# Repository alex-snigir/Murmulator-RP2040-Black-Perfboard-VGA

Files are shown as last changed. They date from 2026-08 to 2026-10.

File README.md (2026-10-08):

*Read this document in English: [README_EN.md](README_EN.md)*

# Мурмулятор — RP2040 Black Clone, VGA-сборка на перфборде

Сборка Мурмулятора (переходной платы от Raspberry Pi Pico / клона YD-RP2040 к периферии) с VGA-выходом, PS/2-клавиатурой, двумя джойстик-портами (с поддержкой Bluetooth-геймпадов через BlueRetro), аудиовыходом, аудиовходом для загрузки программ, слотом MicroSD и внешним питанием. Плата собирается на перфборде, схема разведена в KiCad.

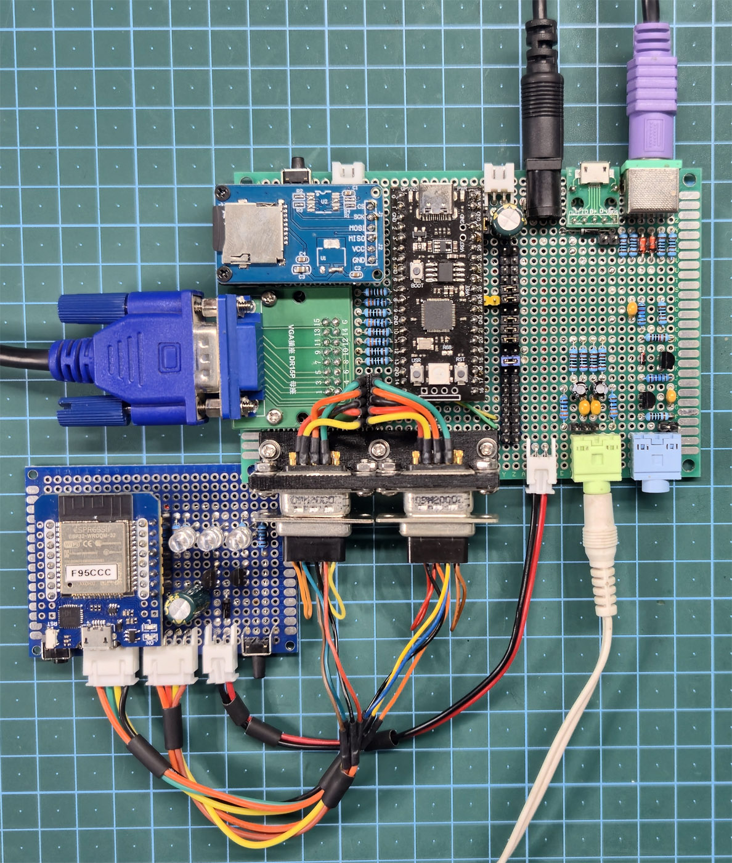
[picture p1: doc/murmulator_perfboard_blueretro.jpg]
Murmulator PCB


## Разъёмы платы

| Разъём | Назначение |
|---|---|
| J1 | Внешнее питание (PSU), DC Jack → шина `+5V_RAW` |
| J2 | Отвод шины `+5V_RAW` — для внешней периферии (BlueRetro) |
| J3 | VGA (12-контактная гребёнка, Conn_02x06) |
| J4 | Клавиатура (PS/2, Mini-DIN-6) |
| J5 | Внешний разъём (EXT, 40 пинов); пары пинов с джамперами подключают PS/2, звук и аудиовход к GPIO |
| J6 | Джойстик 1 (DE-9) |
| J7 | Джойстик 2 (DE-9) |
| J8 | Аудиовыход |
| J9 | Аудиовход (загрузка программ с TAP/магнитофона) |
| J10 | Отвод `+3V3` (JST-XH) |
| J11 | Отвод узла `+5V_VOUT` (тот же узел, что и клавиатура J4) |
| J12 | Второй вход питания от USB (модуль Micro USB) вместо DC-джека → через D1 на шину `+5V_RAW` |
| J13 | Селектор (перемычка): `+5V_RAW` → Vin (штатно) или → Vout |
| J14 | Перемычка в обход D1 |
| J15 | Модуль MicroSD (SPI) |
| J16 | Дубль J2 на другой стороне платы |

## Документация

- [`doc/murmulator-vga-project-summary.md`](doc/murmulator-vga-project-summary.md) — полное описание сборки (RU): доработка SD-модуля, VGA, PS/2-клавиатура, джойстики и интеграция BlueRetro, аудиовыход и аудиовход, разъём J5, питание, чек-лист сборки. Английская версия: [`doc/murmulator-vga-project-summary_EN.md`](doc/murmulator-vga-project-summary_EN.md).
- [`doc/rp2040-module-powerchain-analysis.md`](doc/rp2040-module-powerchain-analysis.md) — сравнение цепей питания YD-RP2040 (Black Clone) и официального Raspberry Pi Pico. Английская версия: [`doc/rp2040-module-powerchain-analysis_EN.md`](doc/rp2040-module-powerchain-analysis_EN.md).
- [`doc/Firmware/technocat-murmulator-keyboard-mapping.md`](doc/Firmware/technocat-murmulator-keyboard-mapping.md) — маппинг PS/2-клавиатуры на ZX Spectrum в прошивке Tecnocat v0.96.20, разбор режима «Cursor joystick». Английская версия: [`doc/Firmware/technocat-murmulator-keyboard-mapping_EN.md`](doc/Firmware/technocat-murmulator-keyboard-mapping_EN.md).
- [`doc/murmulator-ps2-modifiers-oscillograms.pdf`](doc/murmulator-ps2-modifiers-oscillograms.pdf) — осциллограммы PS/2-сигналов CLK/DATA для клавиш-модификаторов ([DOCX](doc/murmulator-ps2-modifiers-oscillograms.docx)). Английская версия: [PDF](doc/murmulator-ps2-modifiers-oscillograms_EN.pdf), [DOCX](doc/murmulator-ps2-modifiers-oscillograms_EN.docx).
- [`doc/murmulator_perfboard_front.jpg`](doc/murmulator_perfboard_front.jpg) — фото платы на перфборде (front).
- [`doc/murmulator_perfboard_back.jpg`](doc/murmulator_perfboard_back.jpg) — фото платы на перфборде (back).

## Схемы (KiCad)

- [`schematics/rp2040_black_vga/`](schematics/rp2040_black_vga/) — исходные файлы проекта KiCad.
- [`schematics/rp2040_black_vga/plot/rp2040_black_vga.pdf`](schematics/rp2040_black_vga/plot/rp2040_black_vga.pdf) — принципиальная схема в PDF.
- [`schematics/rp2040_black_vga/plot/rp2040_black_vga.net`](schematics/rp2040_black_vga/plot/rp2040_black_vga.net) — нетлист.

## Справочные материалы

- [`doc/YD-2040-2022-V1.1-Schematics_black_clone.pdf`](doc/YD-2040-2022-V1.1-Schematics_black_clone.pdf) — схема модуля YD-RP2040 (Black Clone).
- [`doc/YD-2040-2022-V1.1 - Powerchain.jpg`](<doc/YD-2040-2022-V1.1 - Powerchain.jpg>), [`doc/RP2040 Official Pico Module - Powerchain.jpg`](<doc/RP2040 Official Pico Module - Powerchain.jpg>) — фрагменты схем питания клона и официального Pico.
- [`doc/original_classic_murmulator_37NJU22_emul_RPPICO_card.pdf`](doc/original_classic_murmulator_37NJU22_emul_RPPICO_card.pdf) — оригинальная классическая схема Мурмулятора.
- [`doc/FT SD Module modification.jpg`](<doc/FT SD Module modification.jpg>) — доработка SD-модуля.

## Ключевые особенности сборки

- **SD-модуль** доработан: выпаяны AMS1117 и буфер 74VHCT125A, установлены перемычки — модуль работает как чистый 3.3V breakout без потери фронтов на высокой скорости SPI.
- **VGA** — пассивная резисторная R2R-лесенка на GPIO, без отдельного питания.
- **PS/2-клавиатура** — питание от Vout (после диода BAT54C), сигнальные линии CLK/DATA согласованы по уровню резистивно-зенерной схемой (5V → 3.3V).
- **Джойстики (Dendy, DE-9)** — сдвиговый регистр запитан от 3.3V, что снимает необходимость в защитных резисторах на DATA.
- **BlueRetro** — DIY-адаптер на ESP32 эмулирует оба джойстик-порта по Bluetooth HID (PS3/4/5, Xbox, Wii/Switch и др.), протокол CLOCK/LATCH/DATA идентичен физическому Dendy-джойстику. Требует питания на J1 или J12. Сборка адаптера на 3.3V-логике: https://github.com/alex-snigir/BlueRetro-3.3V-logic
- **Аудиовыход** — стереоканал (L/R) плюс подмешивание сигнала пищалки (BEEP_OUT).
- **Аудиовход** — двухкаскадный формирователь на транзисторах для загрузки программ с TAP-сигнала (магнитофон, телефон, онлайн-плеер TAP).
- **Питание** — шина `+5V_RAW` от DC-джека J1 или от Micro USB J12 (через диод Шоттки D1), селектор J13 подаёт её на Vin модуля (штатно, через встроенный BAT54C) или напрямую на Vout в обход маломощного BAT54C.

Подробности по каждому пункту — в [`doc/murmulator-vga-project-summary.md`](doc/murmulator-vga-project-summary.md).

## Корпус

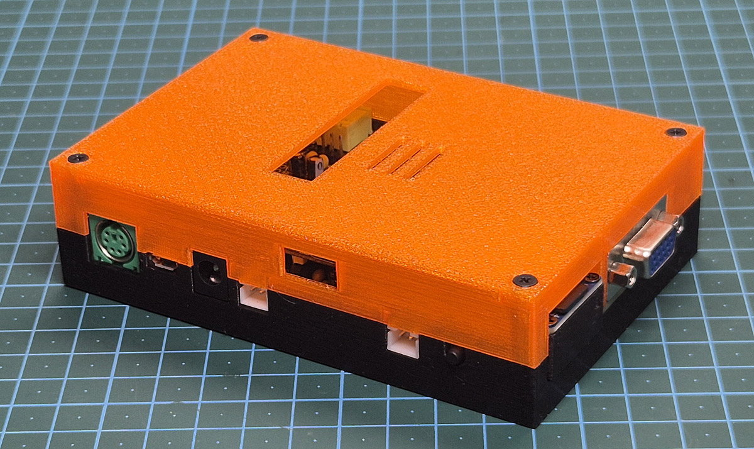
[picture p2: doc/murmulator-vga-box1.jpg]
Murmulator BOX1

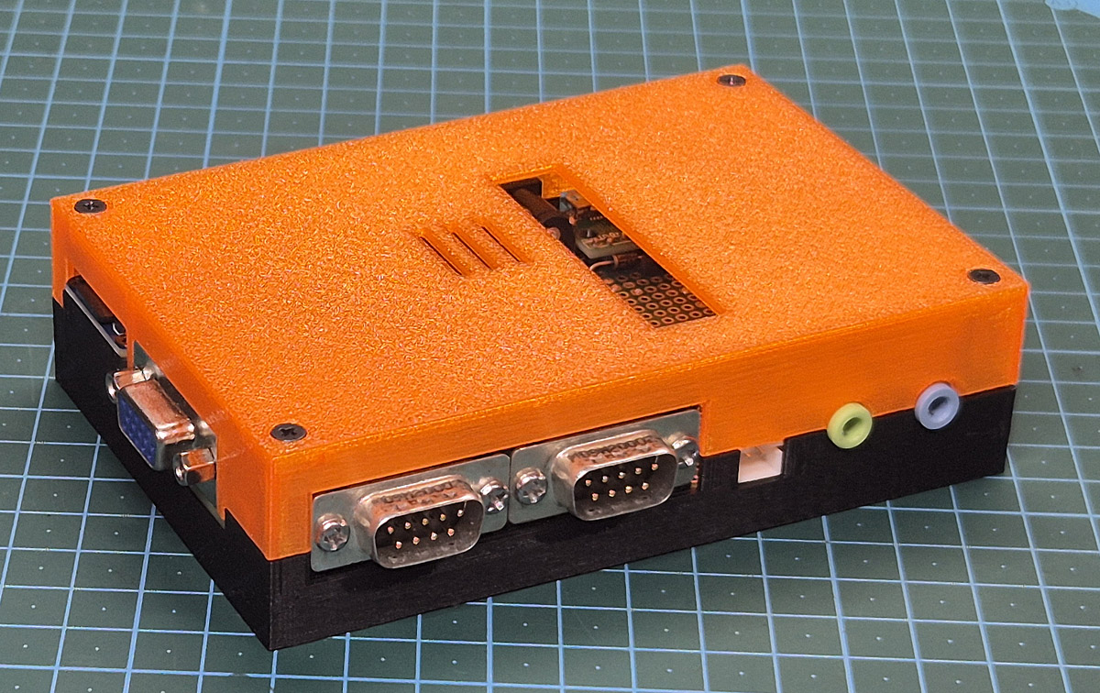
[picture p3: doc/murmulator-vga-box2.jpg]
Murmulator BOX2


### 3D-модели для печати

Файлы лежат в папке [`3d models/`](<3d models/>):

| Деталь | Файлы |
|---|---|
| Корпус (дно + крышка) | [`Box_Bottom_v2.STL`](<3d models/Box_Bottom_v2.STL>) + [`Box_Cover_v2.STL`](<3d models/Box_Cover_v2.STL>) |
| Только плоское дно, без крышки | [`Box_Bottom.STL`](<3d models/Box_Bottom.STL>) |
| Крепление для двух разъёмов DB9 (джойстики J6/J7) | [`DB9_x2_mount.STL`](<3d models/DB9_x2_mount.STL>) |
| Опора для SD-модуля | [`SD_module_support.STL`](<3d models/SD_module_support.STL>) |

Рядом лежат исходники SolidWorks (`.SLDPRT`) и проекты слайсера (`.3mf`) с теми же именами.

## Ссылки

- Официальная документация и другие варианты сборки Мурмулятора: https://murmulator.ru/howto
- Классическая схема (референс): https://github.com/AlexEkb4ever/MURMULATOR_classical_scheme
- Базовая версия «Мурмулятор на макетной плате 7×9 с VGA»: https://murmulator.ru/mm-maket
- BlueRetro-адаптер на 3.3V-логике (интеграция джойстик-портов): https://github.com/alex-snigir/BlueRetro-3.3V-logic
- Прошивка Tecnocat (Murmulator_rp2040): https://github.com/MadedCat/Murmulator_rp2040

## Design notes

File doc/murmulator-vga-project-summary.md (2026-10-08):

# Сборка VGA-Мурмулятора на перфборде

**Версия документа:** 1.0 · **Дата:** 2026-10-03

## 1. Общая концепция

Мурмулятор — плата-переходник от Raspberry Pi Pico к периферии (SD-карта, VGA, PS/2-клавиатура, джойстик, аудиозагрузка).

**Обозначения разъёмов на плате:**

| Разъём | Назначение |
|---|---|
| J1 | Внешнее питание (PSU), DC Jack → шина `+5V_RAW` |
| J2 | Отвод шины `+5V_RAW` — для внешней периферии, напр. BlueRetro |
| J3 | VGA (12-контактная гребёнка, Conn_02x06) |
| J4 | Клавиатура (PS/2, Mini-DIN-6) |
| J5 | Внешний разъём (external connector) |
| J6 | Джойстик 1 (DE-9) |
| J7 | Джойстик 2 (DE-9) |
| J8 | Аудиовыход (audio out) |
| J9 | Аудиовход (audio in) |
| J10 | Отвод `+3V3` (JST-XH, 2 пина: GND, +3V3) |
| J11 | Доп. отвод узла `+5V_VOUT` («Power 5V Out») — для внешней периферии, запитанной после диодного ИЛИ (тот же узел, что и клавиатура J4) |
| J12 | Второй вход питания от USB (модуль Micro USB) вместо DC-джека → через D1 на шину `+5V_RAW` |
| J13 | Селектор (перемычка): `+5V_RAW` → Vin (1–2, штатное положение) или → Vout (2–3) |
| J14 | Перемычка в обход D1 (когда диод не нужен) |
| J15 | Подключение модуля MicroSD (SPI, питание +3V3) |
| J16 | Дубль J2 (отвод `+5V_RAW`) на другой стороне PCB |

**Материалы:**
- Схема и документация: https://murmulator.ru/howto
- Страница класической схемы: https://github.com/AlexEkb4ever/MURMULATOR_classical_scheme

**Базовая версия:** сборка изначально опирается на документацию официального варианта «Мурмулятор на макетной плате 7×9 с VGA» — https://murmulator.ru/mm-maket (архив документации: https://file.murmulator.ru/data/murmulator-types/mm-maket/mm-docs.zip). Текущая версия расширяет её дополнительными функциями, оставаясь на перфборде.

**Связанные документы проекта:**
- `blueretro-murmulator-project-summary.md` — полная детализация DIY-сборки адаптера BlueRetro (выбор ESP32-платы, входная защита питания, LED-индикация, прошивка, осциллографическая проверка), согласована с разделом 5.1 ниже.
- `blueretro-murmulator-user-guide.md` — инструкции по пейрингу/отключению Bluetooth-геймпадов.

---

## 2. Доработка SD-модуля (AMS1117 + 74VHCT125A)

Стандартный дешёвый SD-модуль (5V/3.3V, SPI) требует доработки — иначе просадки/сбои при высокой скорости SPI.

| Элемент | Действие | Зачем |
|---|---|---|
| **AMS1117** (стабилизатор 3.3V) | Выпаять; подать 3.3V от Pico напрямую на площадку, где был выход стабилизатора (VCC карты) | Лишнее звено — Pico и так выдаёт чистые 3.3V, регулятор только добавляет просадку |
| **74VHCT125A** (буфер SPI, SOIC/TSSOP-14) | Выпаять; закоротить перемычками вход→выход на линиях SCK, MOSI, CS (и MISO, если тоже через буфер) | Задержка распространения сигнала через буфер портит фронты на высокой скорости SPI, из-за чего SD-карта сбоит |

**Порядок работ:**
1. Прозвонить мультиметром, какие дорожки на конкретном экземпляре модуля идут через каждую микросхему (ревизии отличаются).
2. Выпаять AMS1117 и 74VHCT125A **до** установки модуля на перфборд (удобнее работать феном/паяльником).
3. Запаять перемычки на месте выпаянных элементов.
4. Прозвонить на отсутствие КЗ между соседними дорожками.
5. Только после этого подключать питание 3.3V и линии SPI от Pico.

**Итог:** модуль превращается из «5V-адаптера с level-shifting» в чистый breakout SD-карты на 3.3V, без активных/пассивных элементов между Pico и картой на линиях данных.

**Подключение модуля MicroSD — разъём J15** (по нетлисту `rp2040_black_vga.net` от 2026-08-29):

| Пин J15 | Сигнал | GPIO Pico |
|---|---|---|
| 1 | GND | — |
| 2 | VCC | `+3V3` |
| 3 | MISO | GP4 |
| 4 | MOSI | GP3 |
| 5 | SCK | GP2 |
| 6 | CS | GP5 |

### 2.1. Pull-up резисторы на линиях SD-модуля

После выпайки 74VHCT125A нужно отдельно проверить/обеспечить подтяжку на двух линиях SPI:

| Линия | Нужна подтяжка? | Номинал | Зачем |
|---|---|---|---|
| **CS** | Да, обязательно | ~10 кОм к 3.3V | При неопределённом состоянии GPIO на старте Pico линия CS должна оставаться высокой (deselected), иначе карта может ловить шум с MOSI/CLK как команды |
| **MISO (DO)** | Желательно | ~10–50 кОм к 3.3V | Когда CS неактивен, выход карты уходит в Hi-Z — подтяжка не даёт линии «плавать» и наводить помехи |
| **MOSI, SCK** | Не требуется | — | Всегда активно управляются мастером (Pico), в Hi-Z не уходят |

**Что проверить на конкретном модуле:**
Некоторые дешёвые SD-модули разводят pull-up прямо возле буфера 74VHCT125A. После его выпайки и установки перемычек резисторы могли:
1. остаться в цепи независимо от буфера — тогда всё ок;
2. пропасть вместе с посадочным местом буфера — тогда нужно добавить отдельно.

**Порядок проверки:** прозвонить омметром между CS и 3.3V, и между MISO и 3.3V (заодно с проверкой на КЗ после перемычек из п.2). Конечное сопротивление (10–50 кОм) — резистор на месте. Обрыв — впаять 10 кОм резисторы от CS и MISO к шине 3.3V на перфборде.

**Подтверждено по нетлисту (`rp2040_black_vga.net`):** подтяжки уже заведены в схему — R28 (10 кОм) на CS (GP5) и R27 (10 кОм) на MISO (GP4), обе к сети `+3V3`. Соответствует рекомендации выше (CS ~10 кОм обязательно, MISO 10–50 кОм желательно).

*Симптом отсутствующей подтяжки CS: карта нестабильно определяется при старте («работает через раз»), что сложно диагностировать постфактум.*

---

## 3. VGA (J3)

- Резисторная R2R-лесенка на цифровые GPIO Pico — пассивная схема, отдельного питания не требует.
- VGA-разъём проще не покупать, а срезать готовый экранированный шлейф со старой видеокарты (часто там разъём есть, но не распаян).
- Резисторы паять компактно, вплотную к шлейфу/разъёму, короткими выводами — критично для чистоты картинки (наводки).

---

## 4. Клавиатура (PS/2, J4)

**Разъём:** J4 — Mini-DIN-6 (PS/2).

### 4.1. Питание клавиатуры

Клавиатура запитывается **отдельно от основной 3.3V-периферии**, напрямую с **Vout (пин 40 YD-RP2040)** — узла после диодного ИЛИ BAT54C, а не с 3V3(OUT). Подробнее — см. раздел 9 («Питание платы»).

| Параметр | Значение |
|---|---|
| Источник | Vout (после BAT54C), не 3V3(OUT) |
| Номинальное падение | ~0.3–0.45V на BAT54C относительно входного 5V (в штатном положении J13; при питании от J12 добавляется падение на D1, см. раздел 10) |
| Итоговое напряжение на пине 4 Mini-DIN-6 | 4.62–4.67V при питании от USB Type-C модуля или от J1 (измерено, в пределах допуска PS/2-спецификации); 4.04–4.29V при питании от J12 через D1 — см. измерения в разделе 10 |
| Ток потребления клавиатуры | ~100 мА (учитывать при бюджетировании тока через BAT54C, см. раздел 10) |

### 4.2. Сигнальные линии (level-shifting 5V → 3.3V)

PS/2 CLK и DATA — 5V-логика на стороне клавиатуры, GPIO Pico — 3.3V, не толерантны к 5V. Используется **пассивная схема** согласования уровней: pull-up резистор + последовательный резистор + зенер-клампа на каждой линии.

**Соответствие сигналов (по референсной схеме MURMULATOR_classical_scheme, KiCad):**

| Сигнал (raw, 5V, от клавиатуры) | После зенер-клампа | GPIO Pico |
|---|---|---|
| PS2 CLK (Mini-DIN-6, pin 5) | PS2_CLK_3V | GP0 |
| PS2 DATA (Mini-DIN-6, pin 1) | PS2_DATA_3V | GP1 |

**Фактическая схема линии (подтверждено по нетлисту `rp2040_black_vga.net`):**

```
J4 (5V raw) ──[R9/R10, 1 кОм, pull-up к +5V_VOUT]── узел CLK/DATA ──[R11/R12, 100 Ом]── GPIO (GP0/GP1) ──[D2/D3, зенер]── GND
```

| Элемент | Номинал | Роль |
|---|---|---|
| R9 (CLK) / R10 (DATA) | 1 кОм | Pull-up сырой 5V-линии к +5V_VOUT — обязателен, т.к. выход клавиатуры open-collector |
| R11 (CLK) / R12 (DATA) | 100 Ом | Последовательный резистор между сырой линией и GPIO — ограничивает ток через зенер при пробое, вместе с ёмкостью входа GPIO образует RC-фильтр |
| D2 (CLK) / D3 (DATA) | 3.3V | Катод на GPIO, анод на GND — клипирует верхний уровень сигнала на GPIO |

Схема: сырой 5V-сигнал (уже подтянутый к +5V_VOUT резистором R9/R10) → проходит через последовательный резистор R11/R12 (100 Ом) → зенер-клампа ограничивает верхний уровень на самом GPIO → сигнал поступает на GP0/GP1.

**Подключение к GPIO — через джамперы на J5 (по нетлисту `rp2040_black_vga.net` от 2026-10-03):** узлы `PS/2_DATA_3V` и `PS/2_CLK_3V` (после R11/R12, на катодах D2/D3) на плате не соединены с GPIO напрямую — они выведены на J5 (пины 29 и 31), а рядом выведены GP1 (пин 30) и GP0 (пин 32). Соединение выполняется джамперами J5:29–30 (DATA → GP1) и J5:31–32 (CLK → GP0); на схеме они обозначены перемычками NT5/NT6 (символы «Exclude from board», в нетлист и на плату не попадают).

---

## 5. Джойстики (Dendy, 2 порта, DE-9, J6/J7)

**Обозначения разъёмов на плате:** Джойстик 1 — **J6**, Джойстик 2 — **J7**.

Используются джойстики типа Dendy (9-pin, узкий разъём) — внутри активная микросхема сдвигового регистра (тип CD4021 или аналог), а не просто механические контакты.

**Распиновка DE-9 (Dendy 9-pin):**

| Пин DE-9 | Назначение |
|---|---|
| 2 | DATA — выход сдвигового регистра |
| 3 | LATCH — защёлка/сброс счётчика |
| 4 | CLOCK — тактовый импульс сдвига |
| 6 | +5V — штатное питание микросхемы регистра |
| 8 | GND |

**Почему регистр запитан от 3.3V, а не от штатных 5V:**
DATA-выход джойстика повторяет уровень его питания. При питании от 5V линия DATA становится 5V-логикой, а GPIO RP2040 не толерантны к 5V (макс. ~3.6V) — потребовался бы защитный резистор (~1 кОм) на DATA как грубое ограничение тока в защитный диод порта. Микросхемы регистра (CD4021-подобные) — обычная КМОП-логика с широким диапазоном питания (обычно 3–18V), поэтому запитка от 3.3V вместо 5V — штатное и безопасное решение: DATA получается сразу 3.3V-логикой, резистор не нужен, подключение к GPIO — напрямую.

**Итоговая схема подключения (2 порта):**

| Сигнал | Джойстик 1 (пин DE-9) | Джойстик 2 (пин DE-9) | GPIO Pico |
|---|---|---|---|
| DATA | 2 | 2 | GP16 (J6) / GP17 (J7) — раздельные |
| LATCH | 3 | 3 | GP15 — общий для обоих портов |
| CLOCK | 4 | 4 | GP14 — общий для обоих портов |
| VCC | 6 | 6 | 3.3V — общая шина |
| GND | 8 | 8 | GND — общая шина |

CLOCK и LATCH — общие для обоих джойстиков (оба регистра тактируются и защёлкиваются синхронно), DATA — обязательно раздельные линии на каждый порт, иначе выходы конфликтуют на одной линии.

**Распиновка джойстиков и прошивка — проверено:** прошивка Tecnocat работает с BlueRetro на текущем подключении (GP14 CLOCK, GP15 LATCH, GP16/GP17 DATA) без правки конфига. Ранее отмеченный открытый вопрос закрыт.

### 5.1. Интеграция BlueRetro (Bluetooth-геймпады вместо физических Dendy-джойстиков)

> 📄 **Полная детализация сборки BlueRetro** (выбор платы, входная защита питания, кнопка BOOT, LED-индикация, версия прошивки, осциллографическая проверка сигналов) вынесена в отдельный документ **`blueretro-murmulator-project-summary.md`**. Ниже — согласованная с ним сводка, достаточная для контекста основной сборки Мурмулятора.

Физических Dendy-джойстиков в проекте нет — оба DE-9-порта (J6/J7) изначально задуманы как **виртуальные**, обслуживаемые одним самодельным DIY-адаптером **BlueRetro** (ESP32, прошивка с github.com/darthcloud/BlueRetro — репозиторий заархивирован владельцем 14.12.2025, активной разработки больше нет, но релизы прошивки и документация остаются доступны).

**Используемая плата: ESP32 D1 mini (MH-ET LIVE, USB-serial чип CH9102).** Выбрана после сравнения с 30-pin WROOM DevKit (отпала — физически не выведен GPIO0, нужный для BOOT/pairing BlueRetro) и с 38-pin WROOM DevKit (технически пригодна и соответствует официальной рекомендации автора BlueRetro, но не выбрана — потребовала бы переделки уже готовой KiCad-схемы). Известный компромисс — встроенный AMS1117 на D1 mini греется до ~54°C, близко к температуре размягчения PLA корпуса; решение по охлаждению сознательно отложено (риск принят). Подробности выбора — в `blueretro-murmulator-project-summary.md`.

**Совместимость с Bluetooth-геймпадами:** BlueRetro работает по стандартному Bluetooth HID (BR/EDR и LE) и поддерживает PS3/PS4/PS5, Xbox One, Xbox Series X|S, Wii/Switch и generic HID BT-устройства.

**Протокол сигналов не отличается от физического Dendy-джойстика:** и Dendy, и NES/Famicom, и выход BlueRetro в режиме FC/NES используют один и тот же принцип сдвигового регистра (CLOCK/LATCH/DATA), поэтому Мурмулятор не отличает физический джойстик от эмулируемого BlueRetro.

**Направление сигналов:** протокол Nintendo PISO (Parallel-In, Serial-Out) — **консоль (в данном случае Мурмулятор/RP2040) генерирует CLOCK и LATCH**, контроллер (физический Dendy-регистр или эмулирующий его BlueRetro) — пассивная сторона, которая только отвечает на них сигналом **DATA**. Поэтому у BlueRetro ESP32 сигналы OUT0 (LATCH) и CUP (CLOCK) — это **входы**, принимающие сигнал от Pico, а не выходы; единственный сигнал, который генерирует сам ESP32 — это **DATA**.

**Соответствие ESP32 (BlueRetro, режим FC/NES) → DE-9 → GPIO Pico:**

| Сигнал | Направление | Нога ESP32 (BlueRetro) | System Pin (станд. NES 7-pin) | DE-9 J6 pin | DE-9 J7 pin | GPIO Pico |
|---|---|---|---|---|---|---|
| LATCH (общий, OUT0) | Pico → ESP32 (вход) | IO32 | 3 | 3 | 3 | GP15 |
| CLOCK порт 1 (P1_CUP) | Pico → ESP32 (вход) | IO5 | 2 | 4 | — | GP14 |
| CLOCK порт 2 (P2_CUP) | Pico → ESP32 (вход) | IO18 | 2 | — | 4 | GP14* |
| DATA порт 1 (P1_D0) | ESP32 → Pico (выход) | IO19 | 4 | 2 | — | GP16 |
| DATA порт 2 (P2_D0) | ESP32 → Pico (выход) | IO22 | 4 | — | 2 | GP17 |
| GND | — | GND ESP32 | 1 | 8 | 8 | GND |
| VCC (+5V, NES pin 7) | — | — | 7 | 6 | 6 | не подключать |

*\*CLOCK для J6 и J7 — это один и тот же сигнал с одного выхода Pico (GP14), физически разведённый на два входа ESP32 (IO5 и IO18). Поскольку источник один (Pico, master), а ESP32 в обоих случаях — только приёмник (вход), это стандартная и безопасная топология «один драйвер — несколько приёмников»: конфликта шин или рассинхронизации сигналов быть не может, отдельной проверки осциллографом перед объединением линий не требуется.*

**VCC (pin 6, DE-9) не используется:** ESP32 внутри BlueRetro нативно работает на 3.3V-логике (совпадает с уже принятым решением по питанию джойстикового узла от 3.3V — см. выше), сигнальные линии CLOCK/LATCH/DATA заводятся на GPIO Pico напрямую, без level-shifter'ов (которые в официальных сборках BlueRetro нужны только для согласования с реальной 5V-консолью NES).

**Питание самого модуля ESP32 (BlueRetro) — отдельно от питания DE-9-портов.** DE-9 pin 6 (VCC) на обоих портах остаётся на **3.3V**, как и было изначально решено для физических Dendy-джойстиков (см. выше) — питание BlueRetro через сигнальный разъём не заводится, чтобы сохранить совместимость портов с физическим джойстиком в будущем.

ESP32-модуль (**DevKit со встроенным стабилизатором AMS1117**, 5V→3.3V на самой плате модуля) запитывается от главной платы через разъём **J2** (JST-XH, отвод шины `+5V_RAW`; дубль — J16 на другой стороне PCB, см. раздел 10) → проводом → разъём **J3** платы BlueRetro. На самой плате BlueRetro J3 — штатный вход питания, уже защищённый собственным диодом Шоттки **D1 = 1N5819** (включён между J3 и входом 5V ESP32, U1 пин 35). Итог — BlueRetro питается от шины `+5V_RAW` через собственный диод Шоттки, без нагрузки на встроенный BAT54C модуля YD-RP2040 и без пересечения с токовым бюджетом клавиатуры на Vout (в штатном положении J13). Стабилизатор на борту DevKit-платы сам понижает пришедшие ~4.5–4.6V (после падения на диоде) до 3.3V для ESP32; отдельного внешнего регулятора на перфборде не требуется.

**⚠️ Ограничение: BlueRetro/джойстики работают только при питании через шину `+5V_RAW` — от J1 (DC-джек) или J12 (Micro USB).** Шина `+5V_RAW` запитана только от этих двух входов — в отличие от Vout (узла после BAT54C), куда сходятся USB Type-C модуля и Vin и который питает клавиатуру независимо от способа питания платы. На YD-RP2040 нет доступного "сырого" USB VBUS до диода (в отличие от оригинальной Pico, где VBUS выведен отдельным пином) — USB Type-C модуля заведён через тот же BAT54C, что и Vin, и наружу выведен только объединённый Vout. Поэтому при питании платы только от USB Type-C самого модуля (без J1/J12) — ESP32/BlueRetro и, соответственно, оба джойстика работать не будут. Для работы с BlueRetro-джойстиками питание нужно подавать на J1 или J12.

**Почему не от Vout (пин 40) RP2040:** Vout на YD-RP2040 — узел сразу после диодного ИЛИ на **BAT54C**, сигнальном диоде с лимитом тока ~150–300 мА на плечо (см. раздел 9–10). Этот узел уже частично нагружен: PS/2-клавиатура (раздел 4) питается именно от Vout и потребляет порядка ~100 мА в режиме ожидания, с возможными всплесками при активности. ESP32 с активным Bluetooth-радио добавил бы ещё пиково 200–300 мА через тот же диод — суммарный ток почти гарантированно превысил бы номинал BAT54C, особенно при совпадении пиков (нажатие клавиши + передача BT-пакета одновременно). Поэтому ESP32 запитывается напрямую от шины 5V, в обход Vin/Vout/BAT54C, не деля этот узел с клавиатурой.

**Пиковое потребление ESP32 — измерено:** мультиметром зафиксировано **~155 мА** по шине 5V при активном BT-радио. Так как ESP32 запитан через J2 (главная плата) → J3 (BlueRetro), в обход BAT54C и узла Vout, эта нагрузка не делит бюджет тока с PS/2-клавиатурой и не ограничена номиналом BAT54C (~150–300 мА на плечо) — запас по току достаточен. Открытый вопрос по этому пункту закрыт.

**LED-индикация состояния (реализована):** вывод **IO17** — global-status LED (пейринг/ошибка, синий, двухрезисторная fail-safe схема), дополнительно разведены два port-status LED на **IO2/IO4** (зелёные, через MOSFET 2N7000, т.к. IO2/IO4/IO17 — strapping-пины ESP32). Логика: при пейринге global-LED и LED первого свободного порта пульсируют; при подключении геймпада соответствующий port-LED загорается ровно (solid). Полная схема, номиналы резисторов и измеренные Vf — в `blueretro-murmulator-project-summary.md`.

**Проверено осциллографом (согласуется с таблицей выше):** CLOCK (GP14→IO5/IO18) — 12.5 кГц, скважность 50%; LATCH (GP15→IO32) — период 1200 мкс, импульс 40 мкс; DATA — инверсная логика (LOW = кнопка нажата), импульс 80 мкс на такт. Подтверждён канонический NES-порядок бит (A, B, Select, Start, Up, Down, Left, Right) для геймпада Xbox One. Топология «один драйвер (Pico) — приёмники (ESP32)» на объединённых CLOCK-линиях подтверждена электрически, без конфликта шины.

**Прошивка:** `v25.04_hw1.zip` (HW1-спецификация, файл `BlueRetro_hw1_nes.bin`), прошивается через `pio pkg exec -- esptool.py`. Входная защита питания модуля BlueRetro (разъём J3, диод D1=1N5819, кнопка RESET SW2, развязывающие конденсаторы) и детали кнопки BOOT/IO0 (внешний pull-up R1=10кОм) — см. `blueretro-murmulator-project-summary.md`.

---

## 6. Аудиовыход (audio out, J8)

**Разъём:** J8 — выходной аудиоджек (L/R). **J8B (OUT_A)** — дублирующая гребёнка (PinHeader), запараллеленная с J8, для удобного подключения аудиовыхода отдельным проводом/шлейфом (например, если корпус/проводка не позволяют использовать сам джек напрямую, или для тестовых измерений).

**Распиновка J8B (OUT_A):**

| Пин J8B | Сигнал | Соответствует |
|---|---|---|
| 1 | L | тот же узел, что и L на джеке J8 |
| 2 | GND | общая земля (тот же узел, что и S на джеке J8) |
| 3 | R | тот же узел, что и R на джеке J8 |

**GPIO-назначение:**

| Net | GPIO Pico | Канал |
|---|---|---|
| LEFT_OUT | GP27 | Левый канал (игровой звук) |
| RIGHT_OUT | GP26 | Правый канал (игровой звук) |
| BEEP_OUT | GP28 | Пищалка / индикация загрузки TAP, подмешивается в оба канала |

**Подключение к GPIO — через джамперы на J5:** сети `RIGHT_OUT`, `LEFT_OUT` и `BEEP_OUT` на плате не соединены с GPIO напрямую — они выведены на J5 рядом с соответствующими GPIO и соединяются джамперами: J5:21–22 (`RIGHT_OUT` → GP26), J5:23–24 (`LEFT_OUT` → GP27), J5:25–26 (`BEEP_OUT` → GP28). На схеме эти джамперы обозначены перемычками NT2/NT3/NT4 (символы «Exclude from board», в нетлист и на плату не попадают).

**Схема (основные каналы L/R):**

| Канал | Последовательный резистор (GPIO → узел) | Развязывающий конденсатор (узел → джек) | Резистор смещения узла на GND |
|---|---|---|---|
| L | R21, 1 кОм | C4, 10 мкФ | R22, 330 Ом |
| R | R25, 1 кОм | C6, 10 мкФ | R26, 330 Ом |

**Подмешивание пищалки (BEEP_OUT, GP28) в оба канала:**

| Элемент | Номинал | Роль |
|---|---|---|
| R23 | 2 кОм | Сумматор BEEP_OUT → узел L (через C5) |
| R24 | 2 кОм | Сумматор BEEP_OUT → узел R (через C7) |
| C5 | 10 нФ | Связь узла L с шиной подмешивания BEEP |
| C7 | 10 нФ | Связь узла R с шиной подмешивания BEEP |

**Важная особенность по замыслу схемы:** пищалка подмешивается заведомо значительно тише игрового звука — развязывающие конденсаторы в тракте BEEP на три порядка меньше (10 нФ против 10 мкФ у основного канала), а суммирующие резисторы (2 кОм) выше, чем последовательные резисторы основного канала (1 кОм). Это осознанное схемное решение (тихий индикаторный сигнал поверх основного звука), а не ошибка/дисбаланс.

**Настройка прошивки Tecnocat:** по умолчанию вывод звука в SETTINGS установлен в **NONE** — звука на J8 не будет, пока не переключить его вручную на **Beeper+AY**.

---

## 7. Аудиовход (audio in, J9)

**Разъём:** J9 — входной аудиоджек 3.5мм (TRS, `AudioJack3_SwitchTR`). Задействован только **Tip** (в нетлисте — сигнал `/LOAD_IN_L`); контакты **R/RN** (правый канал) никуда не подключены (`unconnected-(J9-PadR)`, `unconnected-(J9-PadRN)`). Вход по факту **монофонический** — как и положено для ленточного/TAP-сигнала (правый и левый каналы TAP-файла обычно идентичны, поэтому используется только один).

**Назначение: загрузка программ.** Аудиовход выполняет ту же роль, что и магнитофонный вход классических 8-битных компьютеров (ZX Spectrum и т.п.) — на J9/J9B1 подаётся аудиосигнал с внешнего источника (магнитофон, телефон/компьютер, воспроизводящий TAP-файл, эмулятор ленты), а схема на транзисторах Q1/Q2 формирует из него цифровой сигнал для загрузки программ.

**J9B1 (IN_A)** — дублирующая 2-контактная гребёнка (PinHeader), запараллеленная с сигналом Tip и GND джека J9 — по аналогии с J8B (раздел 6), для удобного подключения аудиовхода отдельным проводом вместо самого джека.

**Распиновка J9B1 (IN_A):**

| Пин J9B1 | Сигнал | Соответствует |
|---|---|---|
| 1 | LOAD_IN_L (Tip) | тот же узел, что и T на джеке J9 |
| 2 | GND | общая земля (тот же узел, что и S на джеке J9) |

**Транзисторы Q1/Q2 — использован S9014 вместо BC850.** По нетлисту `rp2040_black_vga.net` оба транзистора формирователя (Q1, Q2) промаркированы как **S9014** (NPN, TO-92) — применены как альтернатива **BC850**, указанному в оригинальной классической схеме Мурмулятора (`original_classic_murmulator_37NJU22_emul_RPPICO_card.pdf`, аналогичные позиции Q3/Q4). S9014 и BC850 — сопоставимые по параметрам NPN-транзисторы общего назначения, используемые здесь как компараторный/переключающий каскад, а не как усилитель мощности, поэтому замена не критична к точным параметрам (главное — NPN, схожий hFE и достаточное быстродействие для тактовой частоты TAP-сигнала).

**Схема формирователя (2 каскада на транзисторах, по нетлисту):**

```
J9 (T, Tip) / J9B1 pin1 ──┬── R33, 100R ── GND   (нагрузка входного сигнала)
   (сеть /LOAD_IN_L)      │
                          C11, 100n              (разделительный конденсатор)
                           │
                          R32, 10k
                           │
                          ├── D4 (4148): катод → база Q1, анод → коллектор Q1 (клампирующий диод Б-К)
                           │
                          база Q1 (S9014), эмиттер Q1 → GND
                           │
                          коллектор Q1 ──┬── R29, 10k ── база Q2 (S9014), эмиттер Q2 → GND
                                          │
                                          └── R30, 10k ── узел ──┬── C12, 100n ── GND
                                                                  └── R31, 1k ── коллектор Q2 → LOAD_IN_D
```

Q1 работает как первый каскад-формирователь (переключается между отсечкой и насыщением по входному аудиосигналу, снятому через C11/R32 с Tip), Q2 — второй каскад, дополнительно инвертирующий/усиливающий цифровой фронт. Итоговый сигнал — сеть **LOAD_IN_D**.

**Подключение LOAD_IN_D к GPIO — через джампер J5:17–18.** Сеть `LOAD_IN_D` выведена на J5 (пин 17), рядом выведен GP22 (пин 18); соединение выполняется джампером J5:17–18 (`LOAD_IN_D` → GP22). На схеме он обозначен перемычкой NT1 (символ «Exclude from board», поэтому в нетлисте `rp2040_black_vga.net` от 2026-10-03 сети `LOAD_IN_D` и `GP_22` раздельные). Ранее отмеченный открытый вопрос закрыт.

**Питание коллекторного узла R30/R31 — подтверждено по нетлисту (`rp2040_black_vga.net` от 2026-08-29).** Резисторы R30 и R31 (коллекторные нагрузки Q1 и Q2) подключены к сети `+3V3` — подтяжка к питанию на месте, каскад выдаёт логический уровень 3.3V. Ранее отмеченный открытый вопрос закрыт.

### 7.1. Audio-in verification (проверка загрузки)

Для проверки работоспособности аудиовхода использовался онлайн-плеер TAP-файлов **[iratahack.com/zxtape](https://www.iratahack.com/zxtape/)** — сервис воспроизводит `.tap`-файл как аудиосигнал прямо в браузере (эмулирует сигнал с магнитофонной ленты), который подаётся на J9/J9B1 обычным аудиокабелем с выхода компьютера/телефона.

**Настройки аудиовыхода на ноутбуке:**

Отключите «улучшайзеры» звука — Windows и звуковые драйверы по умолчанию подмешивают в сигнал эквалайзер/пространственные эффекты/шумоподавление, которые искажают форму TAP-сигнала и мешают его корректному распознаванию схемой формирователя (раздел 7):

1. Нажмите `Win + R`, введите `mmsys.cpl` и нажмите Enter.
2. Нажмите правой кнопкой на ваш аудиовыход/динамики/наушники → Properties (Свойства) → вкладка Advanced (Дополнительно).
3. Найдите вкладку **Улучшения** (Signal Enhancements) или **Пространственный звук** (Spatial Sound).
4. Поставьте галочку **«Отключить все звуковые эффекты»** (Disable all enhancements) и выключите Dolby/DTS, если они активны.

**Порядок проверки:**
1. Открыть https://www.iratahack.com/zxtape/ в браузере на устройстве, с которого будет подан сигнал.
2. Загрузить/выбрать нужный `.tap`-файл на сайте.
3. Подключить аудиовыход этого устройства (наушниковый разъём) к J9 (или к дублирующей гребёнке J9B1) аудиокабелем.
4. Запустить воспроизведение на сайте одновременно с командой загрузки в прошивке/эмуляторе Мурмулятора (аналог `LOAD ""` на ZX Spectrum).
5. Убедиться, что программа успешно загрузилась (по индикации BEEP_OUT/пищалке загрузки — см. раздел 6 — и/или по факту запуска загруженной программы).

**Статус:** способ проверки подтверждён — сервис iratahack.com/zxtape использовался как источник TAP-сигнала для загрузки программ через J9.

---

## 8. Внешний разъём (external connector, J5)

**Назначение:** J5 — 40-контактный разъём расширения (EXT), предназначенный для подключения внешних плат/периферии. По конструкции аналогичен разъёму `J2 EXT` из оригинальной классической схемы Мурмулятора (`original_classic_murmulator_37NJU22_emul_RPPICO_card.pdf`, компонент `J2`).

### 8.1. Питание на J5: пины 38/39/40

**В оригинальной схеме (чистая Raspberry Pi Pico):**

| Пин J2 EXT (оригинал) | Подключён к | Пин Pico |
|---|---|---|
| 39, 40 (сдвоены) | **VBUS** — сырое питание, доступно только когда подключён USB | 40 |
| 38 | **VSYS** — объединённый узел (после внутреннего диода Pico), доступен от USB или от VSYS-питания | 39 |

Идея оригинала: внешней плате на J2 дают и «сырой», высокотоковый USB-выход (VBUS, сдвоенный на 2 пина ради тока), и универсальный VSYS-сигнал (доступен независимо от источника питания).

**На YD-RP2040 отдельного «сырого VBUS-только-от-USB» физически нет** (см. раздел 9) — есть только Vin (до объединения) и Vout (после объединения через BAT54C). Прямого 1:1 аналога VBUS не существует.

**Проверено по актуальному нетлисту (`rp2040_black_vga.net` от 2026-10-03): решение принято.**

| Пин J5 | Сеть по нетлисту | Соответствует |
|---|---|---|
| 39 | `/+5V_VOUT` | Vout (U1, пин 40) — переведено, как и планировалось |
| 40 | `/+5V_VOUT` | Vout (U1, пин 40) — переведено, как и планировалось |
| 38 | `/+5V_IN` | Vin (U1, пин 39); в штатном положении J13 (1–2) соединён с шиной `+5V_RAW` — **оставлен на `+5V_IN` намеренно** |

Пины 39 и 40 уже переведены на `+5V_VOUT` (тот же узел, что и клавиатура J4) — работают независимо от источника питания платы, в том числе в режиме «только USB». Пин 38 остался на сети `/+5V_IN` (Vin) — она запитана **только** когда есть питание на шине `+5V_RAW` (J1 или J12) и J13 стоит в штатном положении 1–2 (см. раздел 10), то есть в режиме «только USB Type-C модуля» и в положении J13 2–3 пин 38 обесточен. Это намеренное решение: в режиме USB-only внешней плате на J5 доступны силовые пины 39/40.

```
J5, пины 39/40 ──┐
                   ├── узел +5V_VOUT ── U1, Vout (пин 40)   [уже так в схеме]
J4, пин 4 (клавиатура)┘

J5, пин 38 ── узел +5V_IN ── U1, Vin (пин 39)   [от шины +5V_RAW через J13 в положении 1–2 — см. раздел 10]
```

**Важное ограничение по узлу `+5V_VOUT`:** в режиме «только USB» и в штатном положении J13 (1–2) единственный путь на этот узел — через встроенный сигнальный диод **BAT54C**, лимит ~150–300 мА. На этом узле уже сидит клавиатура (~100 мА в простое, возможны всплески). Суммарный ток клавиатуры + платы на J5 (пины 39/40) в режиме USB-only не должен превышать номинал BAT54C — при значимом токе потребления платы на J5 (сопоставимом, например, с BlueRetro, ~150+ мА) бюджета может не хватить. Нужно оценить/измерить фактическое потребление платы на J5, прежде чем полагаться на этот узел. Внешней платы на J5 пока нет — измерение отложено до её появления.

**Статус:** решение принято — пины 39/40 на `+5V_VOUT`, пин 38 остаётся на `+5V_IN` (по аналогии с пином 38/VSYS в оригинальной схеме, где разделялись «сырой» вход и объединённый выход). Подтверждено по нетлисту.

### 8.2. Остальные пины J5

Пины сигналов/GPIO — по нетлисту `rp2040_black_vga.net`, соответствуют физическим GPIO Pico (аналогично распиновке других разделов — VGA, PS/2, джойстики, аудио). Детали по конкретным сигналам EXT-разъёма — при необходимости уточнить отдельно.

---

## 9. Питание платы: архитектура Vin/Vout и режим USB-only

**Используемый модуль: YD-RP2040** (клон Raspberry Pi Pico). У этой платы **нет пинов VBUS/VSYS** в привычном виде — вместо них выведены **Vin (пин 39)** и **Vout (пин 40)**, а диодное объединение источников уже реализовано на самом модуле через сдвоенный Шоттки-диод **BAT54C**.

- Отдельного блока питания в базовой схеме не требуется — питается всё устройство через сам модуль.
- Вход: USB Type-C на модуле (5V) **или** пин **Vin** (аналог VSYS у оригинальной Pico).
- Встроенный преобразователь на модуле выдаёт стабильные **3.3V** на пин **3V3(OUT)**.
- От 3V3(OUT) запитывается основная периферия на перфборде: доработанный SD-модуль, джойстик (VGA питания не требует — пассивная схема).
- **PS/2-клавиатура (J4) запитывается отдельно — 5V, взятые с пина Vout** (узел после диодов BAT54C, а не с 3V3(OUT)). Это стандартное напряжение питания для PS/2-протокола, поэтому линию питания клавиатуры выводят до стабилизатора 3.3V, а не после него.
  - Линии данных (Data) и синхронизации (Clock) при этом остаются 5V-логикой на стороне клавиатуры, а GPIO модуля — 3.3V, поэтому для сигнальных линий нужен понижающий узел (делитель напряжения или зенер-клампы), отдельно от вопроса питания.

### Vin / Vout вместо VBUS / VSYS

На YD-RP2040 диодное ИЛИ между USB и внешним питанием уже разведено на плате:

```
USB (VBUS) ──[диод 1 в BAT54C]──┐
                                  ├──> Vout (пин 40) ──> [регулятор] ──> 3.3V
Vin (пин 39) ──[диод 2 в BAT54C]─┘
```

| Пин | Что это | Особенности |
|---|---|---|
| **Vout (пин 40)** | Аналог VSYS — узел после диодов, вход стабилизатора 3.3V | Напряжение = тому, что реально приходит с активного источника, минус падение на диоде BAT54C |
| **Vin (пин 39)** | Готовый вход для внешнего питания | Уже соединён через диод BAT54C с Vout — отдельный диод Шоттки не нужен |

**Важно:** как и в случае VBUS/VSYS на оригинальной Pico — если модуль не всегда подключён по USB, брать 5V для периферии напрямую с линии USB нельзя, в моменты питания от Vin эта линия будет обесточена.

**Режим питания только от USB:** поскольку Vout объединяет USB и Vin через BAT54C, вся периферия, запитанная от Vout/3V3(OUT) — клавиатура (раздел 4), SD-модуль (раздел 2), физические джойстики (раздел 5) — работает при питании платы только от USB, без внешнего PSU. Исключение — **BlueRetro**: он запитан через J2/J16 от шины `+5V_RAW`, которая получает питание только от J1 или J12 и не объединена с USB Type-C модуля через BAT54C, поэтому требует питания на J1 или J12 (подробнее — раздел 5.1 и раздел 10).

---

## 10. Внешнее питание (J1/J12/J13/J14, отводы J2/J16/J11): шина +5V_RAW и селектор J13

Для YD-RP2040 дополнительный диод Шоттки для питания самого модуля не требуется — диодное ИЛИ между USB Type-C модуля и Vin уже реализовано на модуле через BAT54C. На плате Мурмулятора внешнее питание собирается на общей шине **`+5V_RAW`**, а куда эта шина подаётся на модуль (Vin или Vout) — выбирается перемычкой-селектором **J13**.

**Схема питания (по нетлисту `rp2040_black_vga.net` от 2026-08-29):**
```
Внешний PSU 5V(+) ──> J1 (DC Jack), пин 1 ─────────────────────┐
                                                                  ├── шина +5V_RAW ──┬── J2 (JST-XH), пин 2   (отвод для внешней периферии, BlueRetro)
J12 (модуль Micro USB), VBUS ── D1 (1N5819, анод→катод) ─────────┘                  ├── J16, пин 2          (дубль J2 на другой стороне PCB)
          └── J14 (перемычка в обход D1) ─────────────────────────┘                  ├── C19 (470мкФ)
                                                                                      └── J13, пин 2 (общий вывод селектора)

J13 (селектор): пин 1 ── /+5V_IN  (U1, Vin, пин 39; J5 пин 38)    ← штатное положение: перемычка 1–2
                пин 3 ── /+5V_VOUT (U1, Vout, пин 40; J4 пин 4; J11 пин 2; J5 пины 39/40)   ← перемычка 2–3

Внешний PSU GND ──> J1, пин 2 / общий GND платы (J12, J2, J16 — GND тоже на общей шине)
```

**Источники `+5V_RAW`:**
- **J1** — DC-джек внешнего PSU, подключён к шине напрямую, без диода.
- **J12** — второй вход питания от USB (модуль Micro USB) вместо DC-джека. Подключён через диод Шоттки **D1 (1N5819)**: анод — VBUS J12, катод — `+5V_RAW`. D1 не даёт напряжению с шины (например, от PSU на J1) уходить обратно в USB-источник на J12.
- **J14** — перемычка в обход D1, когда диод не нужен (например, когда J12 — единственный источник и хочется убрать падение ~0.3–0.45V на D1). При замкнутой J14 защиты от обратного тока в J12 нет — не подключать одновременно PSU на J1 и USB на J12.

**Селектор J13 — куда подаётся `+5V_RAW`:** штатное положение (1–2, `+5V_RAW` → `+5V_IN`) обозначено на схеме перемычкой NT8 (символ «Exclude from board», в нетлист и на плату не попадает).

| Положение J13 | Куда идёт `+5V_RAW` | Путь к `+5V_VOUT` (клавиатура J4, J11, J5:39/40) | Особенности |
|---|---|---|---|
| **1–2 (штатное)** | Vin (U1, пин 39) + J5 пин 38 | Через встроенный BAT54C модуля (Vin → BAT54C → Vout) | Ток на `+5V_VOUT` ограничен BAT54C (~150–300 мА на плечо). Источники RAW и USB Type-C модуля развязаны диодами BAT54C — обратного тока между ними нет |
| **2–3** | Vout (U1, пин 40) напрямую | В обход BAT54C | Ток на `+5V_VOUT` ограничен только источником (и D1 1A, если питание от J12). Vin и J5 пин 38 при этом не запитаны |

**⚠️ Особенность положения 2–3 (подтверждено измерением F, см. ниже):** в этом положении `+5V_RAW` и `+5V_VOUT` — один узел без диода между ними. Если плата питается только от USB Type-C модуля (без J1/J12), Vout (~4.7V после BAT54C) через J13 попадает на шину `+5V_RAW`, то есть на J2/J16 (BlueRetro) и на J1 — нагрузка BlueRetro пойдёт через BAT54C, а напряжение окажется на разъёме DC-джека. Положение 2–3 имеет смысл использовать только при питании от J1/J12.

**Напряжения в положении J13 = 1–2 — измерено мультиметром (2026-10-03):**

| Вариант | Источник | BlueRetro на J16 | VBUS J12 | `+5V_RAW` = `+5V_IN` | `+5V_VOUT` (клавиатура J4) |
|---|---|---|---|---|---|
| A | PSU 5V 1A на J1 | нет | — | 5.10V | 4.67V |
| B | PSU 5V 1A на J1 | да | — | 5.08V | 4.65V |
| C | Зарядное устройство Baseus 30W на J12 (через D1) | нет | 5.04V | 4.72V | 4.29V |
| D | Зарядное устройство Baseus 30W на J12 (через D1) | да | 4.83V | 4.47V | 4.04V (клавиатура работает) |
| E | USB Type-C модуля (от ноутбука) | нет | — | 0V в начале, затем медленно растёт | 4.62V |

**Выводы из измерений:**
- Падение на BAT54C (Vin → Vout) — **~0.43V** во всех вариантах A–D.
- Падение на D1 (1N5819) — **~0.32V** без BlueRetro (C) и **~0.36V** с BlueRetro (D).
- При питании от J12 с нагрузкой BlueRetro VBUS проседает на ~0.21V (5.04 → 4.83V) — просадка на стороне зарядного устройства/кабеля/модуля Micro USB; PSU на J1 под той же нагрузкой проседает лишь на ~0.02V.
- Вариант D — худший случай: `+5V_VOUT` = 4.04V, клавиатура при этом работает; питание BlueRetro в порядке — на пине 3V3 ESP32 D1 mini измерено 3.296V. Поднять напряжение при питании от J12 можно перемычкой J14 (обход D1, ~+0.3V) — в этом случае нельзя одновременно подключать PSU на J1.
- Вариант E: при питании только от USB Type-C модуля шина `+5V_RAW` не запитана, но напряжение на ней медленно растёт — вероятно, обратный ток утечки диодов Шоттки (BAT54C) заряжает ненагруженные конденсаторы C19/C20. При подключённой нагрузке (BlueRetro) это напряжение не удерживается.

**Положение J13 = 2–3 — измерено (2026-10-04), вариант F:** питание от USB Type-C модуля (от ноутбука), без BlueRetro: `+5V_VOUT` = `+5V_RAW` = 4.61V — напряжение Vout действительно попадает на шину `+5V_RAW` (J1, J2, J16). `+5V_IN` (Vin) — ~3.3V сразу после включения и медленно растёт: в этом положении Vin ни к чему не подключён, его заряжает ток утечки BAT54C через ненагруженный C20 (100нФ — поэтому быстрее, чем C19 470мкФ в варианте E). VBUS J12 (J14 разомкнута) — стабильно 4.58V: обратный ток утечки D1 (у 1N5819 он заметно больше, чем у BAT54C) удерживает ненагруженный вход J12 почти на уровне `+5V_RAW`. Оба напряжения — «паразитные», без нагрузочной способности; использовать `+5V_IN`/J5:38 и J12 в этом режиме нельзя.

**Положение J13 = 2–3 — прочие варианты (оценка, не измерялось):**

| Источник | `+5V_VOUT` (напрямую от `+5V_RAW`) |
|---|---|
| J1 (PSU 5V) | ~5.0–5.1V |
| J12 через D1 | ~4.5–4.7V |
| J12 с замкнутой J14 | ~4.8–5.0V |
| Только USB Type-C модуля | 4.61V (измерено, вариант F) |

**Назначение J2 / J16:** отводы шины `+5V_RAW` (J16 — дубль J2 на другой стороне PCB) — используются для питания внешней периферии, в частности адаптера **BlueRetro** (см. раздел 5.1), у которого на собственной плате уже есть свой диод Шоттки D1 = 1N5819 на входе J3. Нагрузка на J2/J16 не проходит через BAT54C модуля.

**Назначение J11:** дополнительный отвод узла `+5V_VOUT` (тот же узел, что и клавиатура J4) — для периферии, которая должна получать 5V из общего узла Vout и работать независимо от того, запитана плата через USB Type-C модуля или через `+5V_RAW` (J1/J12). По токовому бюджету это тот же случай, что и клавиатура: в штатном положении J13 (1–2) и в режиме «только USB» суммарный ток J4 + J11 + J5:39/40 через BAT54C ограничен ~150–300 мА — при заметном потреблении устройства на J11 стоит измерить фактический ток и при необходимости запитать его от J2/J16 или переставить J13 в положение 2–3.

**J11 — подтверждено по нетлисту (`rp2040_black_vga.net` от 2026-08-29):** пин 2 J11 находится в сети `/+5V_VOUT` (вместе с U1 Vout, J4, J5:39/40, R9/R10). Ранее обнаруженная изолированная сеть `/+5V_OUT` устранена, J11 электрически запитан.

**Детали и ограничения:**
- BAT54C — маломощный сигнальный сдвоенный диод, не силовой. Типичный максимальный прямой ток через одно плечо — порядка **150–300 мА** (уточнять по даташиту конкретной маркировки на плате).
- Периферию с заметным током потребления (например, Bluetooth-модуль BlueRetro) следует запитывать через J2/J16 (шина `+5V_RAW`, в обход BAT54C), а не с Vout/J11.
- GND внешнего PSU — напрямую на общий GND платы, без диода.
- Защиты от переполюсовки на J1 нет.

*Примечание: на оригинальной Raspberry Pi Pico (не YD-RP2040) такой встроенной точки для внешнего питания нет — там диодное ИЛИ реализовано только между USB и VSYS, и для внешнего PSU пришлось бы добавлять свой диод Шоттки на VSYS вручную, как описано в даташите Pico, раздел 4.5 «Powering Pico».*

### 10.1. Развязывающие конденсаторы силовых шин (добавлено)

По состоянию на текущую ревизию `rp2040_black_vga.pdf`/`.net` на все три силовые сети добавлена развязка:

| Сеть | Конденсаторы | Комментарий |
|---|---|---|
| `+5V_RAW` (шина J1/J2/J16, после D1 от J12) | C19, 470мкФ (bulk, электролит) | Прямо на входе от DC-джека — гасит просадки/пульсации от внешнего PSU |
| `/+5V_IN` (Vin, пин 39 U1, от `+5V_RAW` через J13) | C20, 100нФ | Локальная керамика прямо у входного пина модуля |
| `/+5V_VOUT` (Vout, пин 40, клавиатура J4, J5:39/40) | C17, 100нФ + C18, 100мкФ (bulk) | Особенно значимо для стабильности узла, к которому подтянуты pull-up PS/2-линий R9/R10 (см. раздел 4.2) |
| `+3V3` | C8, C9, C10, C12, C15 (100нФ) + C16 (100мкФ, bulk) | Локальная развязка у джойстиков (J6/J7), модуля MicroSD (J15), отвода +3V3 (J10) и выхода регулятора U1 |

Проверено по нетлисту: все вторые выводы новых конденсаторов корректно возвращаются на GND, обрывов не найдено. Требует ручной проверки при сборке: номинал напряжения электролитов (рекомендуется ≥16V для 5V-шин, ≥10V для 3.3V) и полярность при пайке (C_Polarized).

---

## 11. Чек-лист порядка сборки

1. [x] Доработать SD-модуль (выпайка AMS1117 + 74VHCT125A, перемычки).
2. [x] Сухая раскладка компонентов на перфборде по блочной схеме из документации базовой версии (см. п.1).
3. [x] Развести шины GND и 3.3V по краям платы отдельными дорожками/проводом.
4. [x] Впаять Pico — предпочтительно на штыревые панельки, не напрямую (удобство замены/перепрошивки).
5. [x] Подключить SPI SD-модуля, VGA R2R-резисторы, PS/2-клавиатуру, джойстик к соответствующим GPIO Pico.
6. [x] Схема внешнего питания — по нетлисту от 2026-08-29: шина `+5V_RAW` от J1 и от J12 (через D1, обход — J14), селектор J13 (Vin — штатно / Vout — в обход BAT54C), отводы J2/J16, см. раздел 10. При сборке проверить мультиметром напряжение на `+5V_VOUT` в используемых вариантах питания.
7. [x] J5: пины 39/40 переведены на `+5V_VOUT`, пин 38 намеренно оставлен на `+5V_IN` — см. раздел 8.1.
8. [x] Сверить расположение разъёмов (VGA, SD, аудио, джойстик) со своим корпусом перед финальной сборкой.
9. [x] Аудиовход (раздел 7): LOAD_IN_D подключается к GP22 джампером J5:17–18 (NT1 на схеме); подтяжка коллекторного узла Q1/Q2 к `+3V3` подтверждена по нетлисту.
10. [x] Развязывающие конденсаторы на шинах `+3V3`, `+5V_RAW`, `+5V_IN`, `+5V_VOUT` — добавлены и проверены по нетлисту, см. раздел 10.1.
11. [x] Сеть пина 2 J11 в KiCad — подтверждено по нетлисту: J11 корректно объединён с `+5V_VOUT`, электрически запитан.

---

## Ссылки

- Все варианты сборки: https://murmulator.ru/types

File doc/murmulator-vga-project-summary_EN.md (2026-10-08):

# Building a VGA Murmulator on Perfboard

**Document version:** 1.0 · **Date:** 2026-10-03

## 1. General Concept

Murmulator is an adapter board from the Raspberry Pi Pico to peripherals (SD card, VGA, PS/2 keyboard, joystick, audio loading).

**Connector labels on the board:**

| Connector | Purpose |
|---|---|
| J1 | External power (PSU), DC Jack → `+5V_RAW` rail |
| J2 | Tap of the `+5V_RAW` rail — for external peripherals, e.g. BlueRetro |
| J3 | VGA (12-pin header, Conn_02x06) |
| J4 | Keyboard (PS/2, Mini-DIN-6) |
| J5 | External connector |
| J6 | Joystick 1 (DE-9) |
| J7 | Joystick 2 (DE-9) |
| J8 | Audio out |
| J9 | Audio in |
| J10 | `+3V3` tap (JST-XH, 2 pins: GND, +3V3) |
| J11 | Additional tap of the `+5V_VOUT` node ("Power 5V Out") — for external peripherals powered after the diode-OR (the same node as keyboard J4) |
| J12 | Second power input from USB (Micro USB module) instead of the DC jack → via D1 to the `+5V_RAW` rail |
| J13 | Selector (jumper): `+5V_RAW` → Vin (1–2, default position) or → Vout (2–3) |
| J14 | Jumper bypassing D1 (when the diode is not needed) |
| J15 | MicroSD module connection (SPI, +3V3 power) |
| J16 | Duplicate of J2 (`+5V_RAW` tap) on the other side of the PCB |

**Materials:**
- Schematic and documentation: https://murmulator.ru/howto
- Classic schematic page: https://github.com/AlexEkb4ever/MURMULATOR_classical_scheme

**Base version:** the build is originally based on the documentation of the official "Murmulator on a 7×9 perfboard with VGA" variant — https://murmulator.ru/mm-maket (documentation archive: https://file.murmulator.ru/data/murmulator-types/mm-maket/mm-docs.zip). The current version extends it with additional features while remaining on perfboard.

**Related project documents:**
- `blueretro-murmulator-project-summary.md` — full details of the DIY BlueRetro adapter build (ESP32 board selection, input power protection, LED indication, firmware, oscilloscope verification), aligned with section 5.1 below.
- `blueretro-murmulator-user-guide.md` — instructions for pairing/disconnecting Bluetooth gamepads.

---

## 2. SD Module Rework (AMS1117 + 74VHCT125A)

The standard cheap SD module (5V/3.3V, SPI) requires rework — otherwise there are voltage drops/failures at high SPI speed.

| Element | Action | Why |
|---|---|---|
| **AMS1117** (3.3V regulator) | Desolder; feed 3.3V from the Pico directly to the pad where the regulator's output used to be (card VCC) | Unnecessary link — the Pico already outputs clean 3.3V, the regulator only adds a voltage drop |
| **74VHCT125A** (SPI buffer, SOIC/TSSOP-14) | Desolder; bridge input→output with jumpers on the SCK, MOSI, CS lines (and MISO, if it also goes through the buffer) | Signal propagation delay through the buffer degrades edges at high SPI speed, causing the SD card to fail |

**Work order:**
1. Use a multimeter to check which traces on the specific module instance run through each chip (revisions differ).
2. Desolder the AMS1117 and 74VHCT125A **before** mounting the module on the perfboard (easier to work with a hot air gun/soldering iron).
3. Solder jumpers in place of the removed components.
4. Check for shorts between adjacent traces.
5. Only after that, connect 3.3V power and the SPI lines from the Pico.

**Result:** the module turns from a "5V adapter with level-shifting" into a clean 3.3V SD card breakout, with no active/passive elements between the Pico and the card on the data lines.

**MicroSD module connection — connector J15** (per the netlist `rp2040_black_vga.net` of 2026-08-29):

| J15 pin | Signal | Pico GPIO |
|---|---|---|
| 1 | GND | — |
| 2 | VCC | `+3V3` |
| 3 | MISO | GP4 |
| 4 | MOSI | GP3 |
| 5 | SCK | GP2 |
| 6 | CS | GP5 |

### 2.1. Pull-up Resistors on the SD Module Lines

After removing the 74VHCT125A, two SPI lines need to be separately checked/provided with pull-ups:

| Line | Pull-up needed? | Value | Why |
|---|---|---|---|
| **CS** | Yes, mandatory | ~10 kΩ to 3.3V | With the Pico's GPIO in an undefined state at startup, the CS line must remain high (deselected), otherwise the card may interpret noise on MOSI/CLK as commands |
| **MISO (DO)** | Recommended | ~10–50 kΩ to 3.3V | When CS is inactive, the card's output goes Hi-Z — a pull-up keeps the line from "floating" and picking up interference |
| **MOSI, SCK** | Not required | — | Always actively driven by the master (Pico), never go Hi-Z |

**What to check on a specific module:**
Some cheap SD modules place pull-ups right next to the 74VHCT125A buffer. After desoldering it and installing jumpers, the resistors may have:
1. stayed in the circuit independently of the buffer — then everything is fine;
2. disappeared along with the buffer footprint — then they need to be added separately.

**Check procedure:** measure with an ohmmeter between CS and 3.3V, and between MISO and 3.3V (together with the short check after the jumpers from step 2). A finite resistance (10–50 kΩ) means the resistor is in place. An open circuit means you need to solder 10 kΩ resistors from CS and MISO to the 3.3V rail on the perfboard.

**Confirmed by the netlist (`rp2040_black_vga.net`):** the pull-ups are already in the schematic — R28 (10 kΩ) on CS (GP5) and R27 (10 kΩ) on MISO (GP4), both to the `+3V3` net. This matches the recommendation above (CS ~10 kΩ mandatory, MISO 10–50 kΩ recommended).

*Symptom of a missing CS pull-up: the card is detected unreliably at startup ("works every other time"), which is hard to diagnose after the fact.*

---

## 3. VGA (J3)

- Resistor R2R ladder on the Pico's digital GPIOs — a passive circuit, needs no separate power.
- It is easier not to buy a VGA connector, but to cut a ready-made shielded cable from an old video card (it often has a connector that is present but not soldered).
- Solder the resistors compactly, close to the cable/connector, with short leads — critical for image cleanliness (interference).

---

## 4. Keyboard (PS/2, J4)

**Connector:** J4 — Mini-DIN-6 (PS/2).

### 4.1. Keyboard Power

The keyboard is powered **separately from the main 3.3V peripherals**, directly from **Vout (pin 40 of the YD-RP2040)** — the node after the BAT54C diode-OR, not from 3V3(OUT). For details, see section 9 ("Board Power").

| Parameter | Value |
|---|---|
| Source | Vout (after BAT54C), not 3V3(OUT) |
| Nominal drop | ~0.3–0.45V across BAT54C relative to the 5V input (in the default J13 position; when powered from J12 the drop across D1 is added, see section 10) |
| Resulting voltage on Mini-DIN-6 pin 4 | 4.62–4.67V when powered from the module's USB Type-C or from J1 (measured, within PS/2 specification tolerance); 4.04–4.29V when powered from J12 via D1 — see the measurements in section 10 |
| Keyboard current draw | ~100 mA (account for it when budgeting current through BAT54C, see section 10) |

### 4.2. Signal Lines (level-shifting 5V → 3.3V)

PS/2 CLK and DATA are 5V logic on the keyboard side, the Pico's GPIOs are 3.3V and not 5V-tolerant. A **passive circuit** is used for level matching: a pull-up resistor + a series resistor + a zener clamp on each line.

**Signal mapping (per the MURMULATOR_classical_scheme reference schematic, KiCad):**

| Signal (raw, 5V, from the keyboard) | After the zener clamp | Pico GPIO |
|---|---|---|
| PS2 CLK (Mini-DIN-6, pin 5) | PS2_CLK_3V | GP0 |
| PS2 DATA (Mini-DIN-6, pin 1) | PS2_DATA_3V | GP1 |

**Actual line circuit (confirmed by the netlist `rp2040_black_vga.net`):**

```
J4 (5V raw) ──[R9/R10, 1 kΩ, pull-up to +5V_VOUT]── CLK/DATA node ──[R11/R12, 100 Ω]── GPIO (GP0/GP1) ──[D2/D3, zener]── GND
```

| Element | Value | Role |
|---|---|---|
| R9 (CLK) / R10 (DATA) | 1 kΩ | Pull-up of the raw 5V line to +5V_VOUT — mandatory, since the keyboard output is open-collector |
| R11 (CLK) / R12 (DATA) | 100 Ω | Series resistor between the raw line and the GPIO — limits current through the zener when it conducts, and together with the GPIO input capacitance forms an RC filter |
| D2 (CLK) / D3 (DATA) | 3.3V | Cathode to GPIO, anode to GND — clips the upper signal level at the GPIO |

Circuit: the raw 5V signal (already pulled up to +5V_VOUT by R9/R10) → passes through the series resistor R11/R12 (100 Ω) → the zener clamp limits the upper level at the GPIO itself → the signal reaches GP0/GP1.

**Connection to the GPIOs — via jumpers on J5 (per the netlist `rp2040_black_vga.net` of 2026-10-03):** the `PS/2_DATA_3V` and `PS/2_CLK_3V` nodes (after R11/R12, at the D2/D3 cathodes) are not connected to the GPIOs directly on the board — they are brought out to J5 (pins 29 and 31), with GP1 (pin 30) and GP0 (pin 32) brought out next to them. The connection is made with jumpers J5:29–30 (DATA → GP1) and J5:31–32 (CLK → GP0); on the schematic they are indicated by the net ties NT5/NT6 ("Exclude from board" symbols, not included in the netlist or on the board).

---

## 5. Joysticks (Dendy, 2 ports, DE-9, J6/J7)

**Connector labels on the board:** Joystick 1 — **J6**, Joystick 2 — **J7**.

Dendy-type joysticks are used (9-pin, narrow connector) — inside is an active shift register chip (CD4021 type or equivalent), not just mechanical contacts.

**DE-9 pinout (Dendy 9-pin):**

| DE-9 pin | Purpose |
|---|---|
| 2 | DATA — shift register output |
| 3 | LATCH — latch/counter reset |
| 4 | CLOCK — shift clock pulse |
| 6 | +5V — standard power for the register chip |
| 8 | GND |

**Why the register is powered from 3.3V rather than the standard 5V:**
The joystick DATA output follows its supply level. When powered from 5V, the DATA line becomes 5V logic, while RP2040 GPIOs are not 5V-tolerant (max ~3.6V) — a protective resistor (~1 kΩ) on DATA would be needed as a crude current limit into the port's protection diode. The register chips (CD4021-like) are ordinary CMOS logic with a wide supply range (typically 3–18V), so powering them from 3.3V instead of 5V is a standard and safe solution: DATA becomes 3.3V logic right away, no resistor is needed, and the connection to the GPIO is direct.

**Final wiring (2 ports):**

| Signal | Joystick 1 (DE-9 pin) | Joystick 2 (DE-9 pin) | Pico GPIO |
|---|---|---|---|
| DATA | 2 | 2 | GP16 (J6) / GP17 (J7) — separate |
| LATCH | 3 | 3 | GP15 — shared by both ports |
| CLOCK | 4 | 4 | GP14 — shared by both ports |
| VCC | 6 | 6 | 3.3V — shared rail |
| GND | 8 | 8 | GND — shared rail |

CLOCK and LATCH are shared by both joysticks (both registers are clocked and latched synchronously), DATA must be a separate line for each port, otherwise the outputs conflict on one line.

**Joystick pinout and firmware — verified:** the Tecnocat firmware works with BlueRetro on the current wiring (GP14 CLOCK, GP15 LATCH, GP16/GP17 DATA) without config changes. The previously noted open question is closed.

### 5.1. BlueRetro Integration (Bluetooth gamepads instead of physical Dendy joysticks)

> 📄 **Full details of the BlueRetro build** (board selection, input power protection, BOOT button, LED indication, firmware version, oscilloscope verification of signals) have been moved to a separate document **`blueretro-murmulator-project-summary.md`**. Below is a summary aligned with it, sufficient for the context of the main Murmulator build.

There are no physical Dendy joysticks in the project — both DE-9 ports (J6/J7) were designed from the start as **virtual**, served by a single homemade DIY **BlueRetro** adapter (ESP32, firmware from github.com/darthcloud/BlueRetro — the repository was archived by the owner on 14.12.2025, there is no more active development, but firmware releases and documentation remain available).

**Board used: ESP32 D1 mini (MH-ET LIVE, CH9102 USB-serial chip).** Chosen after comparison with the 30-pin WROOM DevKit (rejected — GPIO0, needed for BlueRetro BOOT/pairing, is not physically broken out) and the 38-pin WROOM DevKit (technically suitable and matches the BlueRetro author's official recommendation, but not chosen — it would have required reworking the already finished KiCad schematic). A known trade-off is that the onboard AMS1117 on the D1 mini heats up to ~54°C, close to the softening temperature of the PLA enclosure; the cooling decision has been deliberately postponed (risk accepted). Selection details are in `blueretro-murmulator-project-summary.md`.

**Bluetooth gamepad compatibility:** BlueRetro works over standard Bluetooth HID (BR/EDR and LE) and supports PS3/PS4/PS5, Xbox One, Xbox Series X|S, Wii/Switch and generic HID BT devices.

**The signal protocol does not differ from a physical Dendy joystick:** Dendy, NES/Famicom and the BlueRetro output in FC/NES mode all use the same shift-register principle (CLOCK/LATCH/DATA), so the Murmulator cannot tell a physical joystick from one emulated by BlueRetro.

**Signal direction:** the Nintendo PISO (Parallel-In, Serial-Out) protocol — **the console (in this case the Murmulator/RP2040) generates CLOCK and LATCH**, the controller (a physical Dendy register or BlueRetro emulating it) is the passive side that only responds to them with the **DATA** signal. Therefore, on the BlueRetro ESP32 the OUT0 (LATCH) and CUP (CLOCK) signals are **inputs** receiving the signal from the Pico, not outputs; the only signal the ESP32 itself generates is **DATA**.

**ESP32 (BlueRetro, FC/NES mode) → DE-9 → Pico GPIO mapping:**

| Signal | Direction | ESP32 pin (BlueRetro) | System Pin (std. NES 7-pin) | DE-9 J6 pin | DE-9 J7 pin | Pico GPIO |
|---|---|---|---|---|---|---|
| LATCH (shared, OUT0) | Pico → ESP32 (input) | IO32 | 3 | 3 | 3 | GP15 |
| CLOCK port 1 (P1_CUP) | Pico → ESP32 (input) | IO5 | 2 | 4 | — | GP14 |
| CLOCK port 2 (P2_CUP) | Pico → ESP32 (input) | IO18 | 2 | — | 4 | GP14* |
| DATA port 1 (P1_D0) | ESP32 → Pico (output) | IO19 | 4 | 2 | — | GP16 |
| DATA port 2 (P2_D0) | ESP32 → Pico (output) | IO22 | 4 | — | 2 | GP17 |
| GND | — | ESP32 GND | 1 | 8 | 8 | GND |
| VCC (+5V, NES pin 7) | — | — | 7 | 6 | 6 | do not connect |

*\*CLOCK for J6 and J7 is one and the same signal from a single Pico output (GP14), physically routed to two ESP32 inputs (IO5 and IO18). Since there is one source (Pico, master) and the ESP32 is only a receiver (input) in both cases, this is the standard and safe "one driver — multiple receivers" topology: there can be no bus conflict or signal desynchronization, and no separate oscilloscope check is needed before joining the lines.*

**VCC (pin 6, DE-9) is not used:** the ESP32 inside BlueRetro natively runs on 3.3V logic (consistent with the already adopted decision to power the joystick node from 3.3V — see above), the CLOCK/LATCH/DATA signal lines go to the Pico GPIOs directly, without level-shifters (which in official BlueRetro builds are only needed to match a real 5V NES console).

**Power for the ESP32 module itself (BlueRetro) is separate from the DE-9 port power.** DE-9 pin 6 (VCC) on both ports stays at **3.3V**, as originally decided for physical Dendy joysticks (see above) — BlueRetro power is not routed through the signal connector, to keep the ports compatible with a physical joystick in the future.

The ESP32 module (**DevKit with an onboard AMS1117 regulator**, 5V→3.3V on the module board itself) is powered from the main board via connector **J2** (JST-XH, tap of the `+5V_RAW` rail; duplicate — J16 on the other side of the PCB, see section 10) → by wire → connector **J3** of the BlueRetro board. On the BlueRetro board itself, J3 is the standard power input, already protected by its own Schottky diode **D1 = 1N5819** (connected between J3 and the ESP32 5V input, U1 pin 35). The result is that BlueRetro is powered from the `+5V_RAW` rail through its own Schottky diode, with no load on the YD-RP2040 module's onboard BAT54C and no overlap with the keyboard's current budget on Vout (in the default J13 position). The regulator on the DevKit board itself steps down the incoming ~4.5–4.6V (after the diode drop) to 3.3V for the ESP32; no separate external regulator on the perfboard is required.

**⚠️ Limitation: BlueRetro/joysticks work only when powered via the `+5V_RAW` rail — from J1 (DC jack) or J12 (Micro USB).** The `+5V_RAW` rail is powered only from these two inputs — unlike Vout (the node after BAT54C), where the module's USB Type-C and Vin converge and which powers the keyboard regardless of how the board is powered. The YD-RP2040 has no accessible "raw" USB VBUS before the diode (unlike the original Pico, where VBUS is broken out on a separate pin) — the module's USB Type-C goes through the same BAT54C as Vin, and only the combined Vout is brought out. Therefore, when the board is powered only from the module's own USB Type-C (without J1/J12), the ESP32/BlueRetro and, consequently, both joysticks will not work. To work with BlueRetro joysticks, power must be fed to J1 or J12.

**Why not from Vout (pin 40) of the RP2040:** Vout on the YD-RP2040 is the node right after the diode-OR on the **BAT54C**, a signal diode with a current limit of ~150–300 mA per leg (see sections 9–10). This node is already partially loaded: the PS/2 keyboard (section 4) is powered precisely from Vout and draws about ~100 mA at idle, with possible spikes during activity. An ESP32 with an active Bluetooth radio would add another 200–300 mA peak through the same diode — the total current would almost certainly exceed the BAT54C rating, especially when peaks coincide (a key press + a BT packet transmission at the same time). Therefore the ESP32 is powered directly from the 5V rail, bypassing Vin/Vout/BAT54C, without sharing this node with the keyboard.

**ESP32 peak consumption — measured:** a multimeter recorded **~155 mA** on the 5V rail with the BT radio active. Since the ESP32 is powered via J2 (main board) → J3 (BlueRetro), bypassing BAT54C and the Vout node, this load does not share the current budget with the PS/2 keyboard and is not limited by the BAT54C rating (~150–300 mA per leg) — the current margin is sufficient. The open question on this point is closed.

**Status LED indication (implemented):** pin **IO17** — global-status LED (pairing/error, blue, two-resistor fail-safe circuit); in addition, two port-status LEDs are wired on **IO2/IO4** (green, via 2N7000 MOSFETs, since IO2/IO4/IO17 are ESP32 strapping pins). Logic: during pairing, the global LED and the LED of the first free port pulse; when a gamepad connects, the corresponding port LED lights solid. The full circuit, resistor values and measured Vf are in `blueretro-murmulator-project-summary.md`.

**Verified with an oscilloscope (consistent with the table above):** CLOCK (GP14→IO5/IO18) — 12.5 kHz, 50% duty cycle; LATCH (GP15→IO32) — period 1200 µs, pulse 40 µs; DATA — inverted logic (LOW = button pressed), 80 µs pulse per clock. The canonical NES bit order (A, B, Select, Start, Up, Down, Left, Right) is confirmed for the Xbox One gamepad. The "one driver (Pico) — receivers (ESP32)" topology on the joined CLOCK lines is confirmed electrically, with no bus conflict.

**Firmware:** `v25.04_hw1.zip` (HW1 specification, file `BlueRetro_hw1_nes.bin`), flashed via `pio pkg exec -- esptool.py`. BlueRetro module input power protection (connector J3, diode D1=1N5819, RESET button SW2, decoupling capacitors) and details of the BOOT/IO0 button (external pull-up R1=10kΩ) — see `blueretro-murmulator-project-summary.md`.

---

## 6. Audio Out (J8)

**Connector:** J8 — output audio jack (L/R). **J8B (OUT_A)** — a duplicate pin header (PinHeader) in parallel with J8, for convenient connection of the audio output with a separate wire/cable (for example, if the enclosure/wiring does not allow using the jack itself directly, or for test measurements).

**J8B (OUT_A) pinout:**

| J8B pin | Signal | Corresponds to |
|---|---|---|
| 1 | L | the same node as L on jack J8 |
| 2 | GND | common ground (the same node as S on jack J8) |
| 3 | R | the same node as R on jack J8 |

**GPIO assignment:**

| Net | Pico GPIO | Channel |
|---|---|---|
| LEFT_OUT | GP27 | Left channel (game sound) |
| RIGHT_OUT | GP26 | Right channel (game sound) |
| BEEP_OUT | GP28 | Beeper / TAP loading indication, mixed into both channels |

**Connection to the GPIOs — via jumpers on J5:** the `RIGHT_OUT`, `LEFT_OUT` and `BEEP_OUT` nets are not connected to the GPIOs directly on the board — they are brought out to J5 next to the corresponding GPIOs and connected with jumpers: J5:21–22 (`RIGHT_OUT` → GP26), J5:23–24 (`LEFT_OUT` → GP27), J5:25–26 (`BEEP_OUT` → GP28). On the schematic these jumpers are indicated by the net ties NT2/NT3/NT4 ("Exclude from board" symbols, not included in the netlist or on the board).

**Circuit (main L/R channels):**

| Channel | Series resistor (GPIO → node) | Coupling capacitor (node → jack) | Node bias resistor to GND |
|---|---|---|---|
| L | R21, 1 kΩ | C4, 10 µF | R22, 330 Ω |
| R | R25, 1 kΩ | C6, 10 µF | R26, 330 Ω |

**Mixing the beeper (BEEP_OUT, GP28) into both channels:**

| Element | Value | Role |
|---|---|---|
| R23 | 2 kΩ | Summing BEEP_OUT → node L (via C5) |
| R24 | 2 kΩ | Summing BEEP_OUT → node R (via C7) |
| C5 | 10 nF | Couples node L with the BEEP mixing bus |
| C7 | 10 nF | Couples node R with the BEEP mixing bus |

**An important feature by design:** the beeper is deliberately mixed in much quieter than the game sound — the coupling capacitors in the BEEP path are three orders of magnitude smaller (10 nF vs. 10 µF in the main channel), and the summing resistors (2 kΩ) are higher than the series resistors of the main channel (1 kΩ). This is a deliberate circuit decision (a quiet indicator signal on top of the main sound), not an error/imbalance.

**Tecnocat firmware setting:** by default, sound output in SETTINGS is set to **NONE** — there will be no sound on J8 until it is manually switched to **Beeper+AY**.

---

## 7. Audio In (J9)

**Connector:** J9 — 3.5mm input audio jack (TRS, `AudioJack3_SwitchTR`). Only the **Tip** is used (in the netlist — the `/LOAD_IN_L` signal); the **R/RN** contacts (right channel) are not connected anywhere (`unconnected-(J9-PadR)`, `unconnected-(J9-PadRN)`). The input is effectively **mono** — as it should be for a tape/TAP signal (the right and left channels of a TAP file are usually identical, so only one is used).

**Purpose: loading programs.** The audio input serves the same role as the tape input of classic 8-bit computers (ZX Spectrum, etc.) — an audio signal from an external source (tape recorder, phone/computer playing a TAP file, tape emulator) is fed to J9/J9B1, and the circuit on transistors Q1/Q2 shapes it into a digital signal for loading programs.

**J9B1 (IN_A)** — a duplicate 2-pin header (PinHeader) in parallel with the Tip signal and GND of jack J9 — similar to J8B (section 6), for convenient connection of the audio input with a separate wire instead of the jack itself.

**J9B1 (IN_A) pinout:**

| J9B1 pin | Signal | Corresponds to |
|---|---|---|
| 1 | LOAD_IN_L (Tip) | the same node as T on jack J9 |
| 2 | GND | common ground (the same node as S on jack J9) |

**Transistors Q1/Q2 — S9014 used instead of BC850.** In the netlist `rp2040_black_vga.net`, both shaper transistors (Q1, Q2) are marked as **S9014** (NPN, TO-92) — used as an alternative to the **BC850** specified in the original classic Murmulator schematic (`original_classic_murmulator_37NJU22_emul_RPPICO_card.pdf`, equivalent positions Q3/Q4). S9014 and BC850 are comparable general-purpose NPN transistors, used here as a comparator/switching stage rather than a power amplifier, so the substitution is not critical to exact parameters (what matters is NPN, a similar hFE and sufficient speed for the TAP signal clock rate).

**Shaper circuit (2 transistor stages, per the netlist):**

```
J9 (T, Tip) / J9B1 pin1 ──┬── R33, 100R ── GND   (input signal load)
   (net /LOAD_IN_L)       │
                          C11, 100n              (coupling capacitor)
                           │
                          R32, 10k
                           │
                          ├── D4 (4148): cathode → Q1 base, anode → Q1 collector (B-C clamping diode)
                           │
                          Q1 base (S9014), Q1 emitter → GND
                           │
                          Q1 collector ──┬── R29, 10k ── Q2 base (S9014), Q2 emitter → GND
                                          │
                                          └── R30, 10k ── node ──┬── C12, 100n ── GND
                                                                  └── R31, 1k ── Q2 collector → LOAD_IN_D
```

Q1 works as the first shaping stage (switching between cutoff and saturation according to the input audio signal taken via C11/R32 from Tip), Q2 is the second stage, additionally inverting/amplifying the digital edge. The resulting signal is the **LOAD_IN_D** net.

**Connecting LOAD_IN_D to a GPIO — via jumper J5:17–18.** The `LOAD_IN_D` net is brought out to J5 (pin 17), with GP22 brought out next to it (pin 18); the connection is made with jumper J5:17–18 (`LOAD_IN_D` → GP22). On the schematic it is indicated by the net tie NT1 (an "Exclude from board" symbol, so in the netlist `rp2040_black_vga.net` of 2026-10-03 the `LOAD_IN_D` and `GP_22` nets are separate). The previously noted open question is closed.

**Power for the R30/R31 collector node — confirmed by the netlist (`rp2040_black_vga.net` of 2026-08-29).** Resistors R30 and R31 (the collector loads of Q1 and Q2) are connected to the `+3V3` net — the pull-up to power is in place, the stage outputs a 3.3V logic level. The previously noted open question is closed.

### 7.1. Audio-in verification (loading check)

To verify the audio input, the online TAP file player **[iratahack.com/zxtape](https://www.iratahack.com/zxtape/)** was used — the service plays a `.tap` file as an audio signal right in the browser (emulating a tape signal), which is fed to J9/J9B1 with an ordinary audio cable from the computer/phone output.

**Audio output settings on the laptop:**

Disable sound "enhancers" — Windows and audio drivers by default mix equalizer/spatial effects/noise suppression into the signal, which distort the TAP signal waveform and interfere with its correct recognition by the shaper circuit (section 7):

1. Press `Win + R`, type `mmsys.cpl` and press Enter.
2. Right-click your audio output/speakers/headphones → Properties → Advanced tab.
3. Find the **Enhancements** (Signal Enhancements) or **Spatial Sound** tab.
4. Check **"Disable all enhancements"** and turn off Dolby/DTS if they are active.

**Check procedure:**
1. Open https://www.iratahack.com/zxtape/ in the browser on the device the signal will be fed from.
2. Upload/select the desired `.tap` file on the site.
3. Connect this device's audio output (headphone jack) to J9 (or to the duplicate header J9B1) with an audio cable.
4. Start playback on the site simultaneously with the load command in the Murmulator firmware/emulator (the equivalent of `LOAD ""` on the ZX Spectrum).
5. Make sure the program loaded successfully (by the BEEP_OUT/loading beeper indication — see section 6 — and/or by the loaded program actually starting).

**Status:** the verification method is confirmed — the iratahack.com/zxtape service was used as the TAP signal source for loading programs via J9.

---

## 8. External Connector (J5)

**Purpose:** J5 is a 40-pin expansion connector (EXT) intended for connecting external boards/peripherals. By design it is similar to the `J2 EXT` connector from the original classic Murmulator schematic (`original_classic_murmulator_37NJU22_emul_RPPICO_card.pdf`, component `J2`).

### 8.1. Power on J5: pins 38/39/40

**In the original schematic (genuine Raspberry Pi Pico):**

| J2 EXT pin (original) | Connected to | Pico pin |
|---|---|---|
| 39, 40 (doubled) | **VBUS** — raw power, available only when USB is connected | 40 |
| 38 | **VSYS** — combined node (after the Pico's internal diode), available from USB or from VSYS power | 39 |

The idea of the original: the external board on J2 is given both the "raw", high-current USB output (VBUS, doubled on 2 pins for current) and the universal VSYS signal (available regardless of the power source).

**The YD-RP2040 physically has no separate "raw VBUS-from-USB-only"** (see section 9) — there is only Vin (before combining) and Vout (after combining via BAT54C). There is no direct 1:1 equivalent of VBUS.

**Verified against the current netlist (`rp2040_black_vga.net` of 2026-10-03): decision made.**

| J5 pin | Net per netlist | Corresponds to |
|---|---|---|
| 39 | `/+5V_VOUT` | Vout (U1, pin 40) — moved, as planned |
| 40 | `/+5V_VOUT` | Vout (U1, pin 40) — moved, as planned |
| 38 | `/+5V_IN` | Vin (U1, pin 39); in the default J13 position (1–2) connected to the `+5V_RAW` rail — **intentionally left on `+5V_IN`** |

Pins 39 and 40 have already been moved to `+5V_VOUT` (the same node as keyboard J4) — they work regardless of the board's power source, including in USB-only mode. Pin 38 remained on the `/+5V_IN` (Vin) net — it is powered **only** when there is power on the `+5V_RAW` rail (J1 or J12) and J13 is in the default position 1–2 (see section 10), i.e. in "module USB Type-C only" mode and with J13 in position 2–3 pin 38 is unpowered. This is an intentional decision: in USB-only mode the power pins 39/40 are available to the external board on J5.

```
J5, pins 39/40 ──┐
                   ├── node +5V_VOUT ── U1, Vout (pin 40)   [already so in the schematic]
J4, pin 4 (keyboard)──┘

J5, pin 38 ── node +5V_IN ── U1, Vin (pin 39)   [from the +5V_RAW rail via J13 in position 1–2 — see section 10]
```

**Important limitation of the `+5V_VOUT` node:** in USB-only mode and in the default J13 position (1–2) the only path to this node is through the onboard **BAT54C** signal diode, limit ~150–300 mA. The keyboard already sits on this node (~100 mA at idle, spikes possible). The total current of the keyboard + the board on J5 (pins 39/40) in USB-only mode must not exceed the BAT54C rating — with a significant current draw by the board on J5 (comparable, for example, to BlueRetro, ~150+ mA) the budget may not be enough. The actual consumption of the board on J5 needs to be estimated/measured before relying on this node. There is no external board on J5 yet — the measurement is postponed until one appears.

**Status:** decision made — pins 39/40 on `+5V_VOUT`, pin 38 stays on `+5V_IN` (by analogy with pin 38/VSYS in the original schematic, where the "raw" input and the combined output were kept separate). Confirmed by the netlist.

### 8.2. Other J5 Pins

Signal/GPIO pins — per the netlist `rp2040_black_vga.net`, correspond to the Pico's physical GPIOs (similar to the pinout in other sections — VGA, PS/2, joysticks, audio). Details on specific EXT connector signals — to be clarified separately if needed.

---

## 9. Board Power: Vin/Vout Architecture and USB-only Mode

**Module used: YD-RP2040** (a Raspberry Pi Pico clone). This board **has no VBUS/VSYS pins** in the usual form — instead, **Vin (pin 39)** and **Vout (pin 40)** are broken out, and the diode-OR of the sources is already implemented on the module itself via the **BAT54C** dual Schottky diode.

- No separate power supply is required in the base circuit — the whole device is powered through the module itself.
- Input: USB Type-C on the module (5V) **or** the **Vin** pin (the equivalent of VSYS on the original Pico).
- The onboard converter on the module provides a stable **3.3V** on the **3V3(OUT)** pin.
- The main peripherals on the perfboard are powered from 3V3(OUT): the reworked SD module, the joystick (VGA needs no power — passive circuit).
- **The PS/2 keyboard (J4) is powered separately — 5V taken from the Vout pin** (the node after the BAT54C diodes, not from 3V3(OUT)). This is the standard supply voltage for the PS/2 protocol, so the keyboard power line is taken before the 3.3V regulator, not after it.
  - The Data and Clock lines remain 5V logic on the keyboard side, while the module's GPIOs are 3.3V, so the signal lines need a step-down stage (voltage divider or zener clamps), separately from the power question.

### Vin / Vout instead of VBUS / VSYS

On the YD-RP2040, the diode-OR between USB and external power is already routed on the board:

```
USB (VBUS) ──[diode 1 in BAT54C]──┐
                                    ├──> Vout (pin 40) ──> [regulator] ──> 3.3V
Vin (pin 39) ──[diode 2 in BAT54C]─┘
```

| Pin | What it is | Notes |
|---|---|---|
| **Vout (pin 40)** | VSYS equivalent — node after the diodes, input of the 3.3V regulator | Voltage = what actually comes from the active source, minus the drop across the BAT54C diode |
| **Vin (pin 39)** | Ready-made input for external power | Already connected to Vout via a BAT54C diode — no separate Schottky diode needed |

**Important:** as with VBUS/VSYS on the original Pico — if the module is not always connected via USB, you cannot take 5V for peripherals directly from the USB line; when powered from Vin, this line will be unpowered.

**USB-only power mode:** since Vout combines USB and Vin via BAT54C, all peripherals powered from Vout/3V3(OUT) — the keyboard (section 4), the SD module (section 2), physical joysticks (section 5) — work when the board is powered from USB only, without an external PSU. The exception is **BlueRetro**: it is powered via J2/J16 from the `+5V_RAW` rail, which receives power only from J1 or J12 and is not combined with the module's USB Type-C via BAT54C, so it requires power on J1 or J12 (for details — section 5.1 and section 10).

---

## 10. External Power (J1/J12/J13/J14, taps J2/J16/J11): +5V_RAW Rail and the J13 Selector

For the YD-RP2040, an additional Schottky diode to power the module itself is not required — the diode-OR between the module's USB Type-C and Vin is already implemented on the module via BAT54C. On the Murmulator board, external power is collected on a common **`+5V_RAW`** rail, and where this rail is fed into the module (Vin or Vout) is chosen with the jumper selector **J13**.

**Power circuit (per the netlist `rp2040_black_vga.net` of 2026-08-29):**
```
External PSU 5V(+) ──> J1 (DC Jack), pin 1 ────────────────────┐
                                                                  ├── rail +5V_RAW ──┬── J2 (JST-XH), pin 2   (tap for external peripherals, BlueRetro)
J12 (Micro USB module), VBUS ── D1 (1N5819, anode→cathode) ─────┘                  ├── J16, pin 2          (duplicate of J2 on the other side of the PCB)
          └── J14 (jumper bypassing D1) ──────────────────────────┘                  ├── C19 (470µF)
                                                                                      └── J13, pin 2 (common pin of the selector)

J13 (selector): pin 1 ── /+5V_IN  (U1, Vin, pin 39; J5 pin 38)    ← default position: jumper 1–2
                pin 3 ── /+5V_VOUT (U1, Vout, pin 40; J4 pin 4; J11 pin 2; J5 pins 39/40)   ← jumper 2–3

External PSU GND ──> J1, pin 2 / common board GND (J12, J2, J16 — GND also on the common rail)
```

**`+5V_RAW` sources:**
- **J1** — DC jack of the external PSU, connected to the rail directly, without a diode.
- **J12** — a second power input from USB (Micro USB module) instead of the DC jack. Connected through the Schottky diode **D1 (1N5819)**: anode — J12 VBUS, cathode — `+5V_RAW`. D1 prevents voltage from the rail (for example, from the PSU on J1) from flowing back into the USB source on J12.
- **J14** — a jumper bypassing D1 when the diode is not needed (for example, when J12 is the only source and you want to remove the ~0.3–0.45V drop across D1). With J14 closed there is no reverse-current protection for J12 — do not connect a PSU on J1 and USB on J12 at the same time.

**J13 selector — where `+5V_RAW` is fed:** the default position (1–2, `+5V_RAW` → `+5V_IN`) is indicated on the schematic by the net tie NT8 (an "Exclude from board" symbol, not included in the netlist or on the board).

| J13 position | Where `+5V_RAW` goes | Path to `+5V_VOUT` (keyboard J4, J11, J5:39/40) | Notes |
|---|---|---|---|
| **1–2 (default)** | Vin (U1, pin 39) + J5 pin 38 | Through the module's onboard BAT54C (Vin → BAT54C → Vout) | Current to `+5V_VOUT` is limited by BAT54C (~150–300 mA per leg). The RAW source and the module's USB Type-C are isolated by the BAT54C diodes — no reverse current between them |
| **2–3** | Vout (U1, pin 40) directly | Bypassing BAT54C | Current to `+5V_VOUT` is limited only by the source (and by D1 1A when powered from J12). Vin and J5 pin 38 are then unpowered |

**⚠️ Peculiarity of position 2–3 (confirmed by measurement F, see below):** in this position `+5V_RAW` and `+5V_VOUT` are a single node with no diode between them. If the board is powered only from the module's USB Type-C (without J1/J12), Vout (~4.7V after BAT54C) reaches the `+5V_RAW` rail through J13, i.e. J2/J16 (BlueRetro) and J1 — the BlueRetro load will go through BAT54C, and the voltage will appear on the DC jack connector. Position 2–3 makes sense only when powered from J1/J12.

**Voltages with J13 = 1–2 — measured with a multimeter (2026-10-03):**

| Variant | Source | BlueRetro on J16 | J12 VBUS | `+5V_RAW` = `+5V_IN` | `+5V_VOUT` (keyboard J4) |
|---|---|---|---|---|---|
| A | PSU 5V 1A on J1 | no | — | 5.10V | 4.67V |
| B | PSU 5V 1A on J1 | yes | — | 5.08V | 4.65V |
| C | Baseus 30W charger on J12 (via D1) | no | 5.04V | 4.72V | 4.29V |
| D | Baseus 30W charger on J12 (via D1) | yes | 4.83V | 4.47V | 4.04V (keyboard works) |
| E | Module USB Type-C (from a laptop) | no | — | 0V at first, then slowly rising | 4.62V |

**Conclusions from the measurements:**
- Drop across BAT54C (Vin → Vout) — **~0.43V** in all variants A–D.
- Drop across D1 (1N5819) — **~0.32V** without BlueRetro (C) and **~0.36V** with BlueRetro (D).
- When powered from J12 with the BlueRetro load, VBUS sags by ~0.21V (5.04 → 4.83V) — a sag on the charger/cable/Micro USB module side; the PSU on J1 sags by only ~0.02V under the same load.
- Variant D is the worst case: `+5V_VOUT` = 4.04V, and the keyboard still works; BlueRetro power is fine — 3.296V measured on the 3V3 pin of the ESP32 D1 mini. The voltage when powered from J12 can be raised with jumper J14 (bypassing D1, ~+0.3V) — in that case a PSU must not be connected to J1 at the same time.
- Variant E: when powered only from the module's USB Type-C, the `+5V_RAW` rail is not powered, but the voltage on it slowly rises — probably the reverse leakage current of the Schottky diodes (BAT54C) charging the unloaded capacitors C19/C20. With a load connected (BlueRetro) this voltage does not hold.

**J13 = 2–3 position — measured (2026-10-04), variant F:** powered from the module's USB Type-C (from a laptop), no BlueRetro: `+5V_VOUT` = `+5V_RAW` = 4.61V — the Vout voltage does reach the `+5V_RAW` rail (J1, J2, J16). `+5V_IN` (Vin) — ~3.3V right after power-on and slowly rising: in this position Vin is not connected to anything, and it is charged by the BAT54C leakage current through the unloaded C20 (100nF — hence faster than C19 470µF in variant E). J12 VBUS (J14 open) — a steady 4.58V: the reverse leakage current of D1 (noticeably higher for the 1N5819 than for the BAT54C) holds the unloaded J12 input almost at the `+5V_RAW` level. Both voltages are "parasitic", with no load capability; `+5V_IN`/J5:38 and J12 must not be used in this mode.

**J13 = 2–3 position — other variants (estimate, not measured):**

| Source | `+5V_VOUT` (directly from `+5V_RAW`) |
|---|---|
| J1 (PSU 5V) | ~5.0–5.1V |
| J12 via D1 | ~4.5–4.7V |
| J12 with J14 closed | ~4.8–5.0V |
| Module USB Type-C only | 4.61V (measured, variant F) |

**Purpose of J2 / J16:** taps of the `+5V_RAW` rail (J16 is a duplicate of J2 on the other side of the PCB) — used to power external peripherals, in particular the **BlueRetro** adapter (see section 5.1), which already has its own Schottky diode D1 = 1N5819 at the J3 input on its own board. The load on J2/J16 does not pass through the module's BAT54C.

**Purpose of J11:** an additional tap of the `+5V_VOUT` node (the same node as keyboard J4) — for peripherals that should receive 5V from the common Vout node and work regardless of whether the board is powered via the module's USB Type-C or via `+5V_RAW` (J1/J12). In current budget this is the same case as the keyboard: in the default J13 position (1–2) and in USB-only mode, the total current of J4 + J11 + J5:39/40 through BAT54C is limited to ~150–300 mA — if the device on J11 draws noticeable current, the actual current should be measured and, if necessary, it should be powered from J2/J16 or J13 should be moved to position 2–3.

**J11 — confirmed by the netlist (`rp2040_black_vga.net` of 2026-08-29):** J11 pin 2 is on the `/+5V_VOUT` net (together with U1 Vout, J4, J5:39/40, R9/R10). The previously found isolated `/+5V_OUT` net has been eliminated, J11 is electrically powered.

**Details and limitations:**
- BAT54C is a low-power dual signal diode, not a power diode. The typical maximum forward current through one leg is on the order of **150–300 mA** (check against the datasheet for the specific marking on the board).
- Peripherals with noticeable current draw (for example, the BlueRetro Bluetooth module) should be powered via J2/J16 (the `+5V_RAW` rail, bypassing BAT54C), not from Vout/J11.
- External PSU GND — directly to the common board GND, without a diode.
- There is no reverse polarity protection on J1.

*Note: the original Raspberry Pi Pico (not the YD-RP2040) has no such built-in point for external power — there the diode-OR is implemented only between USB and VSYS, and for an external PSU you would have to add your own Schottky diode on VSYS manually, as described in the Pico datasheet, section 4.5 "Powering Pico".*

### 10.1. Power Rail Decoupling Capacitors (added)

As of the current revision of `rp2040_black_vga.pdf`/`.net`, decoupling has been added to all three power nets:

| Net | Capacitors | Comment |
|---|---|---|
| `+5V_RAW` (rail J1/J2/J16, after D1 from J12) | C19, 470 µF (bulk, electrolytic) | Right at the DC jack input — damps drops/ripple from the external PSU |
| `/+5V_IN` (Vin, pin 39 U1, from `+5V_RAW` via J13) | C20, 100 nF | Local ceramic right at the module's input pin |
| `/+5V_VOUT` (Vout, pin 40, keyboard J4, J5:39/40) | C17, 100 nF + C18, 100 µF (bulk) | Especially important for the stability of the node to which the PS/2 line pull-ups R9/R10 are tied (see section 4.2) |
| `+3V3` | C8, C9, C10, C12, C15 (100 nF) + C16 (100 µF, bulk) | Local decoupling at the joysticks (J6/J7), the MicroSD module (J15), the +3V3 tap (J10) and the U1 regulator output |

Verified against the netlist: all second pins of the new capacitors correctly return to GND, no opens found. Requires manual checking during assembly: the voltage rating of the electrolytics (≥16V recommended for 5V rails, ≥10V for 3.3V) and polarity when soldering (C_Polarized).

---

## 11. Assembly Order Checklist

1. [x] Rework the SD module (desolder AMS1117 + 74VHCT125A, jumpers).
2. [x] Dry layout of components on the perfboard according to the block diagram from the base version documentation (see item 1).
3. [x] Route the GND and 3.3V rails along the board edges with separate traces/wire.
4. [x] Solder in the Pico — preferably on pin header sockets, not directly (for easy replacement/reflashing).
5. [x] Connect the SD module SPI, VGA R2R resistors, PS/2 keyboard, joystick to the corresponding Pico GPIOs.
6. [x] External power circuit — per the netlist of 2026-08-29: `+5V_RAW` rail from J1 and from J12 (via D1, bypass — J14), selector J13 (Vin — default / Vout — bypassing BAT54C), taps J2/J16, see section 10. During assembly, check the voltage on `+5V_VOUT` with a multimeter in the power variants used.
7. [x] J5: pins 39/40 moved to `+5V_VOUT`, pin 38 intentionally left on `+5V_IN` — see section 8.1.
8. [x] Check the placement of the connectors (VGA, SD, audio, joystick) against your enclosure before final assembly.
9. [x] Audio input (section 7): LOAD_IN_D is connected to GP22 with jumper J5:17–18 (NT1 on the schematic); the pull-up of the Q1/Q2 collector node to `+3V3` is confirmed by the netlist.
10. [x] Decoupling capacitors on the `+3V3`, `+5V_RAW`, `+5V_IN`, `+5V_VOUT` rails — added and verified against the netlist, see section 10.1.
11. [x] J11 pin 2 net in KiCad — confirmed by the netlist: J11 is correctly merged with `+5V_VOUT`, electrically powered.

---

## Links

- All build variants: https://murmulator.ru/types

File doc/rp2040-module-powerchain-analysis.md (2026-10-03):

# Сравнение power-архитектуры модулей: YD-2040-2022-V1.1 (Black Clone) vs официальный Raspberry Pi Pico

Анализ на основе `RP2040 Official Pico Module — Powerchain.jpg` (раздел 4.4 datasheet Pico), `YD20402022V1.1 — Powerchain.jpg` (схема клона) и основной платы Мурмулятора `rp2040_black_vga.pdf`/`.net` (U1 = «YD-RP2040 TypeC Black Clone»). Дополняет разделы 9–10 `murmulator-vga-project-summary.md` (там — шины на уровне платы Мурмулятора: J1/J2/J4/J5), здесь — то, что происходит **внутри самого модуля** между разъёмом питания и выходом 3V3.

---

## 1. Официальный Raspberry Pi Pico

**Вход:** разъём micro-USB (5-пиновый: VBUS/D+/D-/ID/GND, без CC-резисторов — USB 2.0 Type-B не требует согласования по CC).

**Тракт питания:**

```
VBUS (пин 40) ──┬── R10(5.6к)+R1(10к) делитель ──> GPIO24  (сенс наличия USB-питания)
                 │
                 └── D1 (MBR120VLSFT1G, Шоттки SOD-323) ──> VSYS (пин 39)

VSYS (пин 39) ──> C1 (47мкФ) ──> U2 RT6150B-33GQW (buck-boost SMPS, VIN/VINA)
                                   │
                                   ├── EN ── R8(100к, pull-up) ── тестовая точка TP4 ── GPIO23 (управление режимом SMPS)
                                   ├── PS ── (Power Save select)
                                   └── LX1/LX2 ── L1 (2.2мкГн, 2.3А) ── VOUT ──> C2(47мкФ) ──> 3V3 (пин 36)
```

**Ключевые особенности:**
- Диодное ИЛИ (VBUS→VSYS) реализовано **дискретным** диодом Шоттки D1 (MBR120VLSFT1G) прямо на плате Pico.
- Регулятор — **buck-boost импульсный преобразователь** RT6150B, до 2.3 А, работает в широком диапазоне входного напряжения (~1.8–5.5 В) — поэтому Pico штатно можно питать хоть от 2×AA батарей, хоть от USB.
- GPIO23 и GPIO24 **зарезервированы** под управление питанием (режим SMPS / сенс VBUS) и не доступны как обычные GPIO на «чистом» Pico.
- VSYS дополнительно резистивно делится (не показано на этом фрагменте картинки, но задокументировано в datasheet) и мониторится через ADC3/GPIO29 — «грубый» вольтметр батареи.

---

## 2. YD-2040-2022-V1.1 (Black Clone)

**Вход:** USB Type-C (TYPEC-304-BCP16). В отличие от micro-USB, Type-C **требует** резисторов на линиях CC для согласования с хостом:

```
USB-C  CC1 ── R1 (5.1к) ── GND
       CC2 ── R2 (5.1к) ── GND
       D+/D- ── R3/R4 (27R) ── (сигнальные, не силовые)
       VBUS ──┐
```
Это стандартная UFP-конфигурация «sink», сигнализирующая хосту дефолтные 5 В / до 500 мА — на клоне уже разведено, отдельно добавлять не нужно.

**Тракт питания:**

```
VBUS (из USB-C) ──┐
                    ├── D2 (BAT54C, сдвоенный маломощный Шоттки) ──> V+ ──> F1 (предохранитель) ──> C1(1мкФ) ──> U1 ME6215C33M5G
Vin (пин 39)   ─────┘                                                                                    │
                                                                                                            OUT(5) ──> C2(1мкФ) ──> 3V3 (пин 36)
```

Узел после D2 физически выведен на **пин 40**, там же, где на оригинальном Pico находится VBUS — но электрически это уже объединённый (через диод) узел, отсюда подпись на схеме клона: *«Vout, pin 40 (VBUS position but 4.7V)»*. Совпадает с тем, что уже зафиксировано в `murmulator-vga-project-summary.md` (раздел 9) как эмпирическое ~4.7–4.8 В на клавиатурном узле — подтверждение того же диодного падения по независимому источнику.

**Ключевые особенности:**
- Диодное ИЛИ реализовано **сдвоенным сигнальным** диодом BAT54C (не силовым Шоттки) — маломощнее, чем D1 на оригинальном Pico. Отсюда и ограничение ~150–300 мА на плечо, уже описанное в разделе 10 основного summary.
- Регулятор — **линейный LDO** ME6215C33M5G (типовой ток ~300 мА), а не импульсный buck-boost. Нет катушки индуктивности L1 — площадь платы меньше, но:
  - КПД ниже при большом перепаде вход/выход (греется сильнее на большом токе);
  - максимальный выходной ток ниже (у RT6150 — 2.3 А, у типовых ME6215 — обычно 300–500 мА в зависимости от корпуса/маркировки);
  - входной диапазон уже — LDO не умеет «boost», то есть питание от источника <3.6В (например, от одной Li-ion банки в разряде) не даст стабильных 3.3В, тогда как buck-boost Pico с этим справляется.
- EN (пин 3) не выведен на управляемый GPIO — судя по картинке, регулятор запитан «всегда включён» (заведён статически), никакого софтверного power-gating через GPIO на этом узле нет.
- **GPIO23 и GPIO24 не зарезервированы под power-management** — они выведены на header как обычные GPIO/ADC (GPIO23 виден на разъёме P2, пин 17). Значит:
  - прошивка/примеры кода, которые на оригинальном Pico читают GPIO24 как «USB подключён/нет» или дёргают GPIO23 для управления режимом SMPS (Power Save vs Forced PWM), на этом клоне **не будут работать так же** — там это просто свободная линия ввода-вывода, а не служебный сигнал регулятора;
  - зато на клоне на один полезный GPIO/ADC больше в распоряжении пользовательской схемы, чем на оригинальном Pico.
- Делителя VSYS→ADC3 (мониторинг напряжения питания) на этом фрагменте схемы клона не видно — судя по всему, не реализован (в отличие от Pico, где R2/R5/R6+ADC3 такой мониторинг штатно даёт).

---

## 3. Сверка с основной платой Мурмулятора (`rp2040_black_vga.pdf`, U1)

Нумерация пинов U1 в основной схеме («YD-RP2040 TypeC Black Clone», 40-контактный DIP-профиль) совпадает с распиновкой на картинке клона:

| Сеть на плате Мурмулятора | Пин U1 | Соответствие на Powerchain-картинке клона |
|---|---|---|
| `Vin` | 39 | Vin (39) — вход до диода D2/BAT54C |
| `Vout` (→ `+5V_VOUT`) | 40 | Vout (40) — узел после D2, физически на месте VBUS оригинального Pico |
| `+3V3` | 36 | 3V3 (36) — выход регулятора ME6215C33M5G |
| `RUN` | 30 | RUN (пин 9 на P2-заголовке картинки) |

Совпадение подтверждает, что модуль на плате действительно клон именно этой ревизии (YD-2040-2022-V1.1), а не другая раскладка пинов — полезная проверка перед пайкой.

**Практический вывод для проекта:** на плате Мурмулятора (разделы 9–10 `murmulator-vga-project-summary.md`) внешнее питание собрано на шине `+5V_RAW` (J1 — DC-джек, J12 — Micro USB через D1 1N5819), а селектор J13 позволяет подать эту шину либо на Vin (штатно, через BAT54C), либо напрямую на Vout — **в обход** внутреннего слаботочного BAT54C. Такой обход предусмотрен именно потому, что у клона (в отличие от оригинального Pico с его силовым MBR120) диодное ОРing изначально маломощное — это архитектурное отличие модуля, а не особенность именно платы Мурмулятора. Второй практический момент — линейный регулятор ME6215C33M5G слабее (по току и КПД), чем buck-boost RT6150 у оригинала, поэтому если в будущем на перфборд добавится периферия, тянущая заметный ток именно с `3V3` (пин 36, а не с `+5V_VOUT`), стоит держать в уме более скромный бюджет тока этого узла по сравнению с «настоящим» Pico.

---

*Источники: RP2040 Official Pico Module — Powerchain.jpg (раздел 4.4 Pico datasheet), YD20402022V1.1 — Powerchain.jpg, rp2040_black_vga.pdf/.net (U1).*

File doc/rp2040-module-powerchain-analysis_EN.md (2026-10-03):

# Module Power Architecture Comparison: YD-2040-2022-V1.1 (Black Clone) vs. Official Raspberry Pi Pico

Analysis based on `RP2040 Official Pico Module — Powerchain.jpg` (section 4.4 of the Pico datasheet), `YD20402022V1.1 — Powerchain.jpg` (clone schematic) and the main Murmulator board `rp2040_black_vga.pdf`/`.net` (U1 = "YD-RP2040 TypeC Black Clone"). Complements sections 9–10 of `murmulator-vga-project-summary_EN.md` (which covers the rails at the Murmulator board level: J1/J2/J4/J5); this document covers what happens **inside the module itself** between the power connector and the 3V3 output.

---

## 1. Official Raspberry Pi Pico

**Input:** micro-USB connector (5-pin: VBUS/D+/D-/ID/GND, no CC resistors — USB 2.0 Type-B does not require CC negotiation).

**Power path:**

```
VBUS (pin 40) ──┬── R10(5.6k)+R1(10k) divider ──> GPIO24  (USB power presence sense)
                 │
                 └── D1 (MBR120VLSFT1G, Schottky SOD-323) ──> VSYS (pin 39)

VSYS (pin 39) ──> C1 (47µF) ──> U2 RT6150B-33GQW (buck-boost SMPS, VIN/VINA)
                                   │
                                   ├── EN ── R8(100k, pull-up) ── test point TP4 ── GPIO23 (SMPS mode control)
                                   ├── PS ── (Power Save select)
                                   └── LX1/LX2 ── L1 (2.2µH, 2.3A) ── VOUT ──> C2(47µF) ──> 3V3 (pin 36)
```

**Key features:**
- The diode-OR (VBUS→VSYS) is implemented with a **discrete** Schottky diode D1 (MBR120VLSFT1G) right on the Pico board.
- The regulator is a **buck-boost switching converter** RT6150B, up to 2.3 A, operating over a wide input voltage range (~1.8–5.5 V) — which is why the Pico can officially be powered from 2×AA batteries just as well as from USB.
- GPIO23 and GPIO24 are **reserved** for power management (SMPS mode / VBUS sense) and are not available as regular GPIOs on a "genuine" Pico.
- VSYS is additionally divided resistively (not shown in this fragment of the picture, but documented in the datasheet) and monitored via ADC3/GPIO29 — a "rough" battery voltmeter.

---

## 2. YD-2040-2022-V1.1 (Black Clone)

**Input:** USB Type-C (TYPEC-304-BCP16). Unlike micro-USB, Type-C **requires** resistors on the CC lines for negotiation with the host:

```
USB-C  CC1 ── R1 (5.1k) ── GND
       CC2 ── R2 (5.1k) ── GND
       D+/D- ── R3/R4 (27R) ── (signal, not power)
       VBUS ──┐
```
This is the standard UFP "sink" configuration, signaling to the host the default 5 V / up to 500 mA — already routed on the clone, nothing needs to be added separately.

**Power path:**

```
VBUS (from USB-C) ──┐
                      ├── D2 (BAT54C, dual low-power Schottky) ──> V+ ──> F1 (fuse) ──> C1(1µF) ──> U1 ME6215C33M5G
Vin (pin 39)   ───────┘                                                                                    │
                                                                                                            OUT(5) ──> C2(1µF) ──> 3V3 (pin 36)
```

The node after D2 is physically brought out to **pin 40**, the same place where VBUS is on the original Pico — but electrically it is already the combined (via the diode) node, hence the label on the clone schematic: *"Vout, pin 40 (VBUS position but 4.7V)"*. This matches what is already recorded in `murmulator-vga-project-summary_EN.md` (section 9) as the empirical ~4.7–4.8 V on the keyboard node — confirmation of the same diode drop from an independent source.

**Key features:**
- The diode-OR is implemented with a **dual signal** diode BAT54C (not a power Schottky) — lower power than D1 on the original Pico. Hence the ~150–300 mA per leg limitation already described in section 10 of the main summary.
- The regulator is a **linear LDO** ME6215C33M5G (typical current ~300 mA), not a switching buck-boost. There is no L1 inductor — less board area, but:
  - lower efficiency with a large input/output difference (heats up more at high current);
  - lower maximum output current (RT6150 — 2.3 A, typical ME6215 — usually 300–500 mA depending on package/marking);
  - narrower input range — an LDO cannot "boost", i.e. power from a source <3.6V (for example, from a single discharged Li-ion cell) will not give a stable 3.3V, whereas the Pico's buck-boost handles this.
- EN (pin 3) is not routed to a controllable GPIO — judging by the picture, the regulator is "always on" (tied statically), there is no software power-gating via GPIO on this node.
- **GPIO23 and GPIO24 are not reserved for power management** — they are broken out to the header as regular GPIO/ADC (GPIO23 is visible on connector P2, pin 17). This means:
  - firmware/code examples that on the original Pico read GPIO24 as "USB connected/not connected" or toggle GPIO23 to control the SMPS mode (Power Save vs Forced PWM) **will not work the same way** on this clone — there it is just a free I/O line, not a regulator service signal;
  - on the other hand, the clone has one more useful GPIO/ADC available to the user circuit than the original Pico.
- A VSYS→ADC3 divider (supply voltage monitoring) is not visible in this fragment of the clone schematic — apparently not implemented (unlike the Pico, where R2/R5/R6+ADC3 provide such monitoring as standard).

---
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

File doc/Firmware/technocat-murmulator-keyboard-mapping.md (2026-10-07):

# Murmulator VGA — PS/2 → ZX Spectrum Keyboard Mapping

Справочная таблица маппинга модификаторов и SYMBOL SHIFT-комбинаций для PS/2-клавиатуры на прошивке Tecnocat v0.96.20.

---

## Модификаторы

| PC-клавиша (PS/2) | Scan-код (make) | Функция на ZX Spectrum | Префикс E0? |
|---|---|---|---|
| Left **Shift** | `0x12` | CAPS SHIFT | Нет |
| Right **Shift** | `0x59` | CAPS SHIFT | Нет |
| Left **Ctrl** | `0x14` | SYMBOL SHIFT | Нет |
| Left **Alt** | `0x11` | не проверено | Нет |
| Right **Ctrl** | `E0 0x14` | SYMBOL SHIFT (подтверждено дублирует Left Ctrl) | Да |
| Right **Shift** | `0x59` | Backspace/Delete (наблюдаемое поведение, не CAPS SHIFT) | Нет |
| Right **Alt** | `E0 0x11` | Backspace/Delete (наблюдаемое поведение) | Да |
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

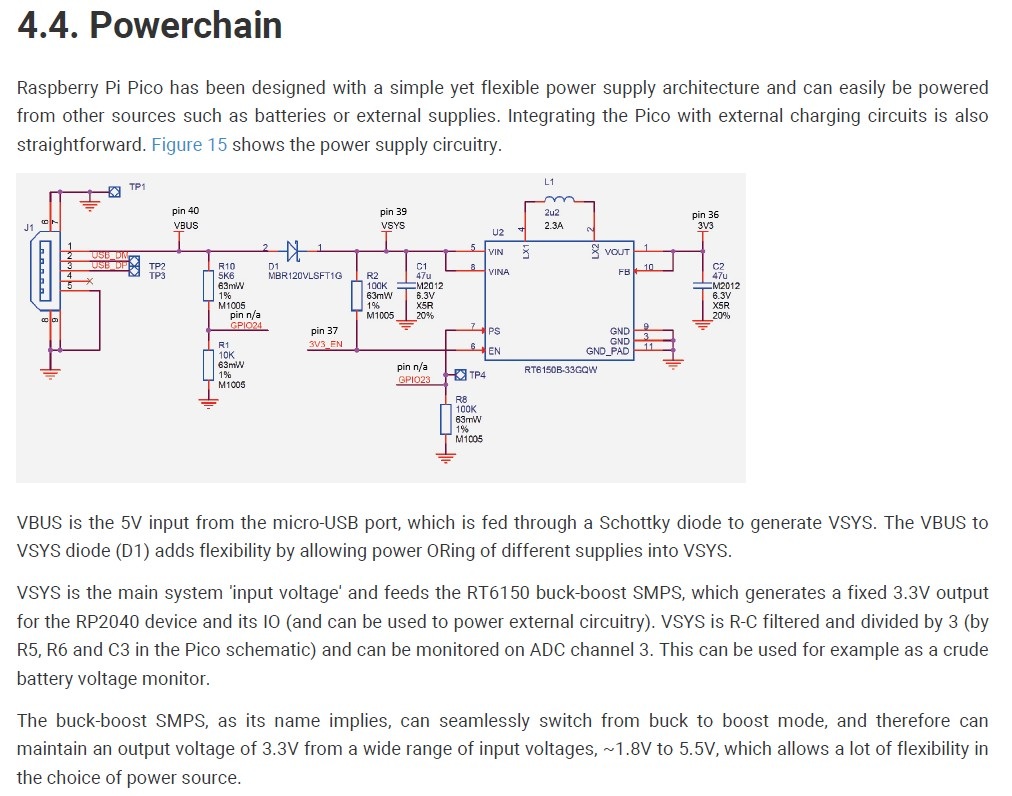
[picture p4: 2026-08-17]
doc/RP2040 Official Pico Module - Powerchain.jpg

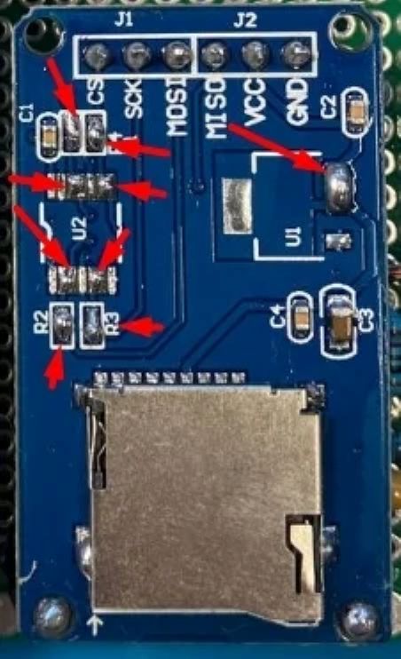
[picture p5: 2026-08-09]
doc/FT SD Module modification.jpg

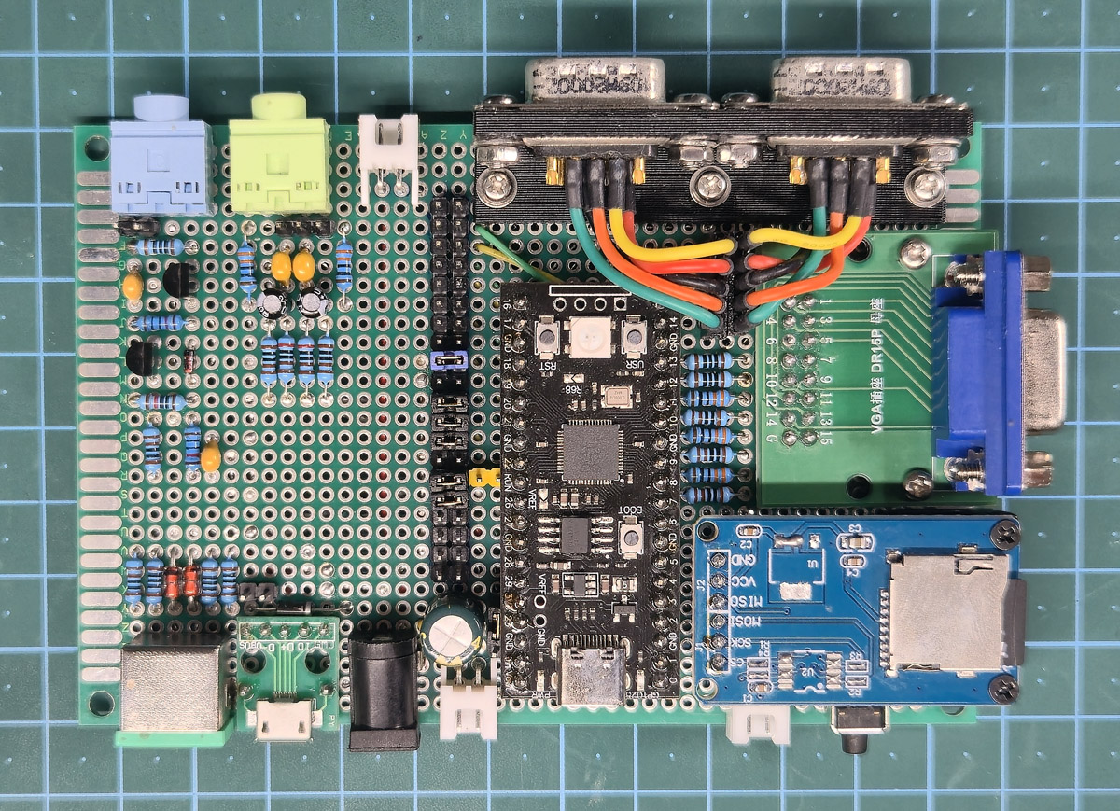
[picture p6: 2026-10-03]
doc/murmulator_perfboard_front.jpg

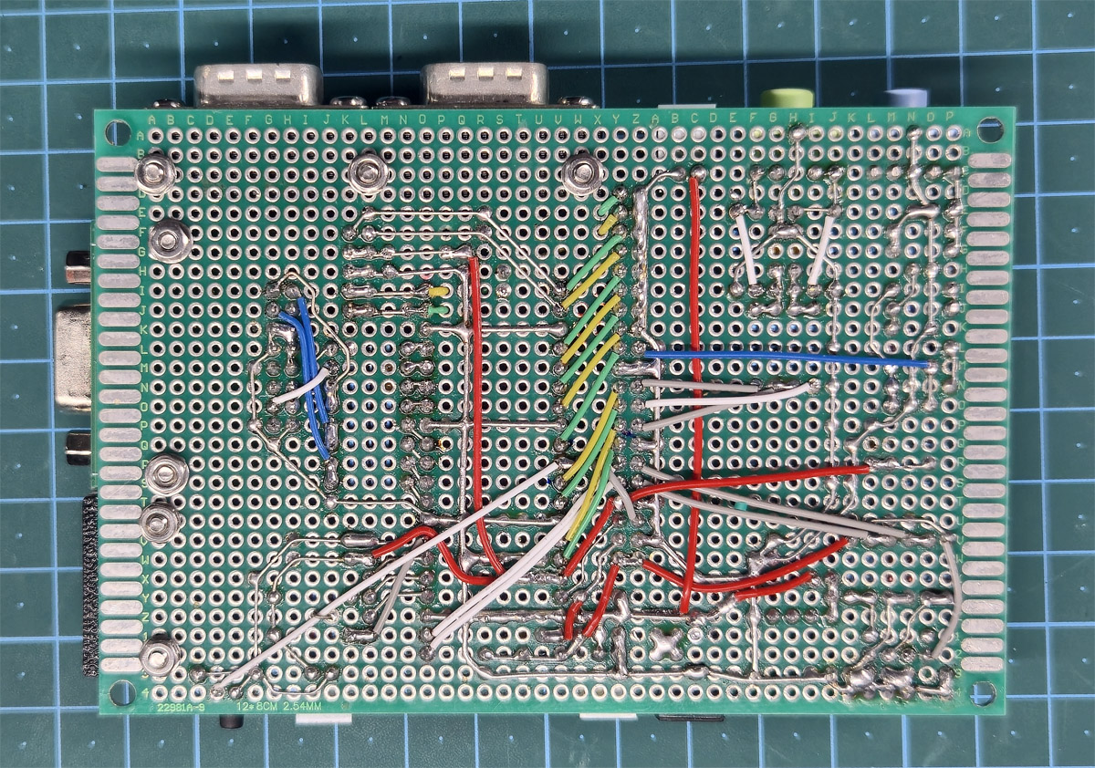
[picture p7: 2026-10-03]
doc/murmulator_perfboard_back.jpg

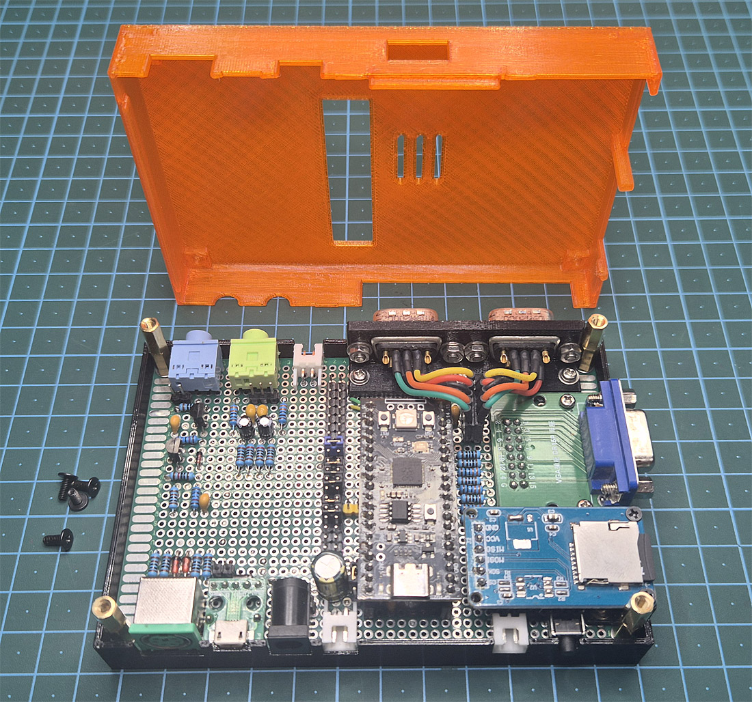
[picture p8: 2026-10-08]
doc/murmulator-vga-box3.jpg

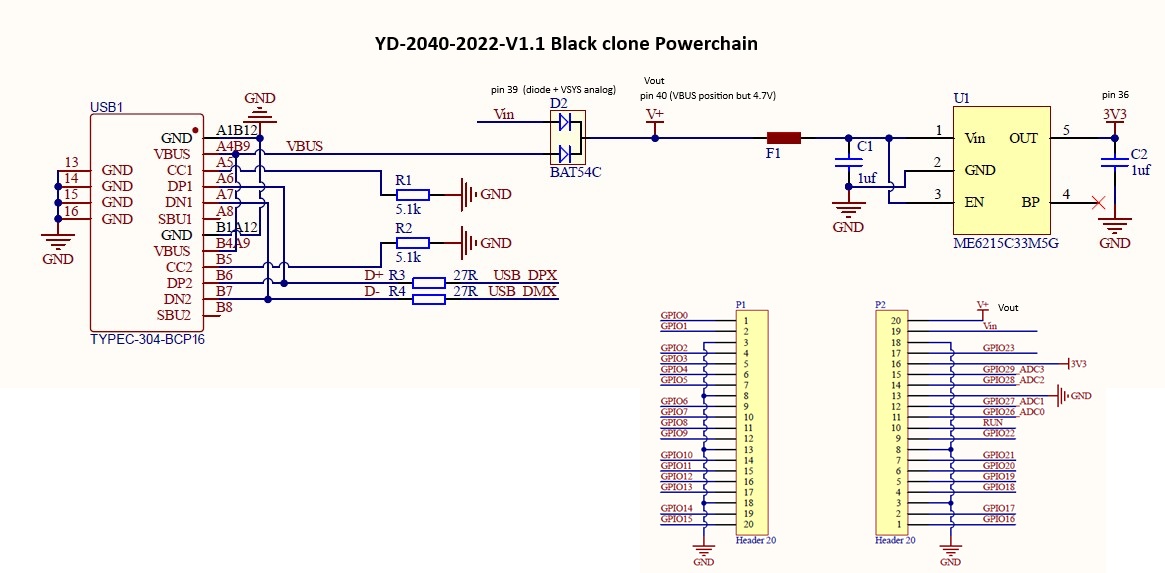
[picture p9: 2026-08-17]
doc/YD-2040-2022-V1.1 - Powerchain.jpg

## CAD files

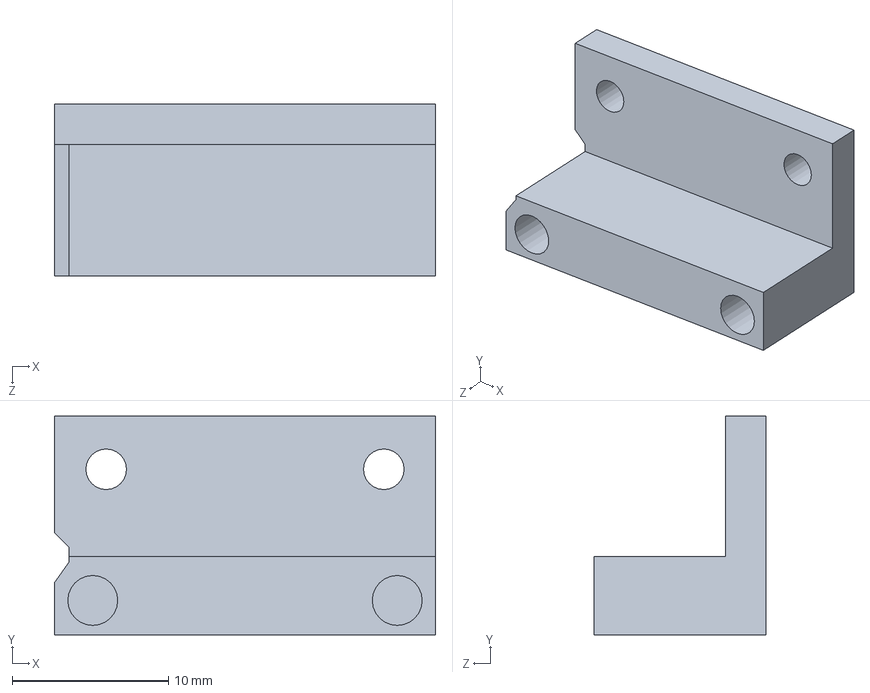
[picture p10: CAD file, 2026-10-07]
3d models/SD_module_support.SLDPRT
24.4 x 14.0 x 11.0 mm

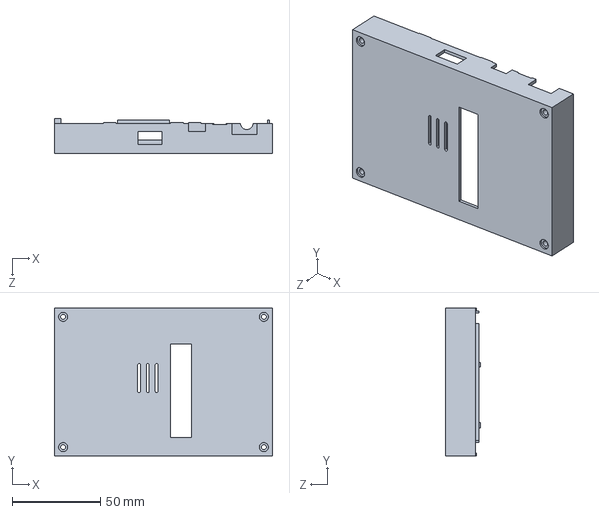
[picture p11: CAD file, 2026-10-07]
3d models/Box_Cover_v2.SLDPRT
123.8 x 83.8 x 19.6 mm

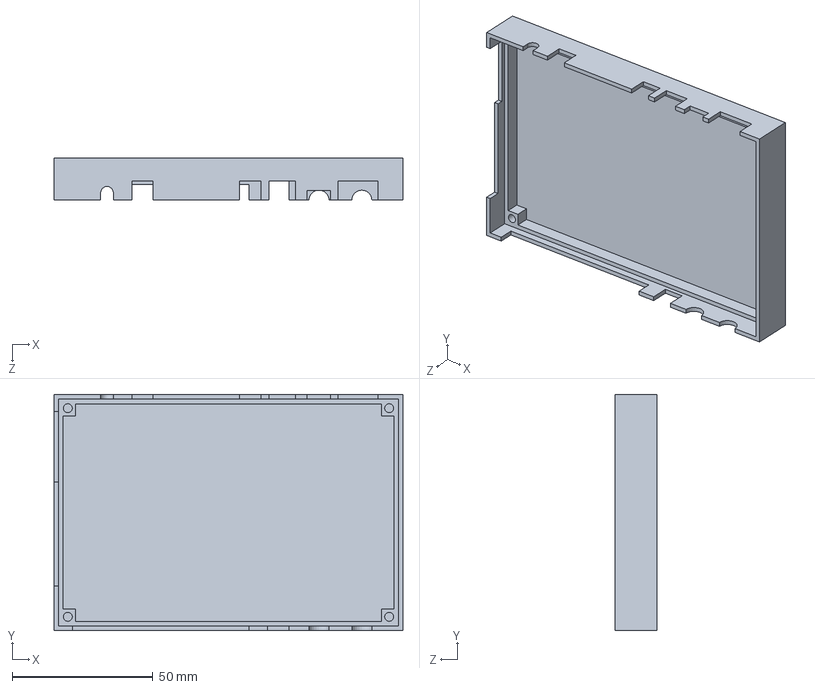
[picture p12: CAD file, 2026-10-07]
3d models/Box_Bottom_v2.SLDPRT
123.8 x 83.8 x 15.0 mm

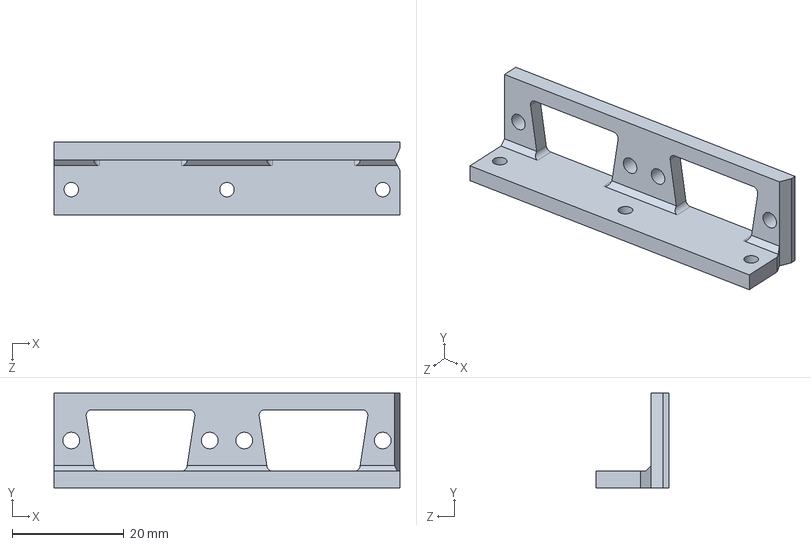
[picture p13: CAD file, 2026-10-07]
3d models/DB9_x2_mount.SLDPRT
62.0 x 17.0 x 13.0 mm

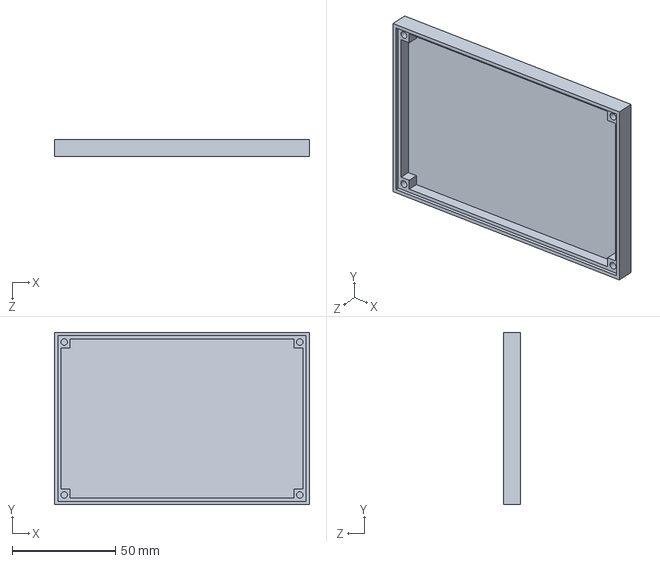
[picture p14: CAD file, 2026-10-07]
3d models/Box_Bottom.SLDPRT
123.4 x 83.4 x 8.20 mm

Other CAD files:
3d models/Box_Bottom.3mf
3d models/Box_Bottom.STL
3d models/Box_Bottom_v2.3mf
3d models/Box_Bottom_v2.STL
3d models/Box_Cover_v2.3mf
3d models/Box_Cover_v2.STL
3d models/DB9_x2_mount.3mf
3d models/DB9_x2_mount.STL
3d models/SD_module_support.3mf
3d models/SD_module_support.STL

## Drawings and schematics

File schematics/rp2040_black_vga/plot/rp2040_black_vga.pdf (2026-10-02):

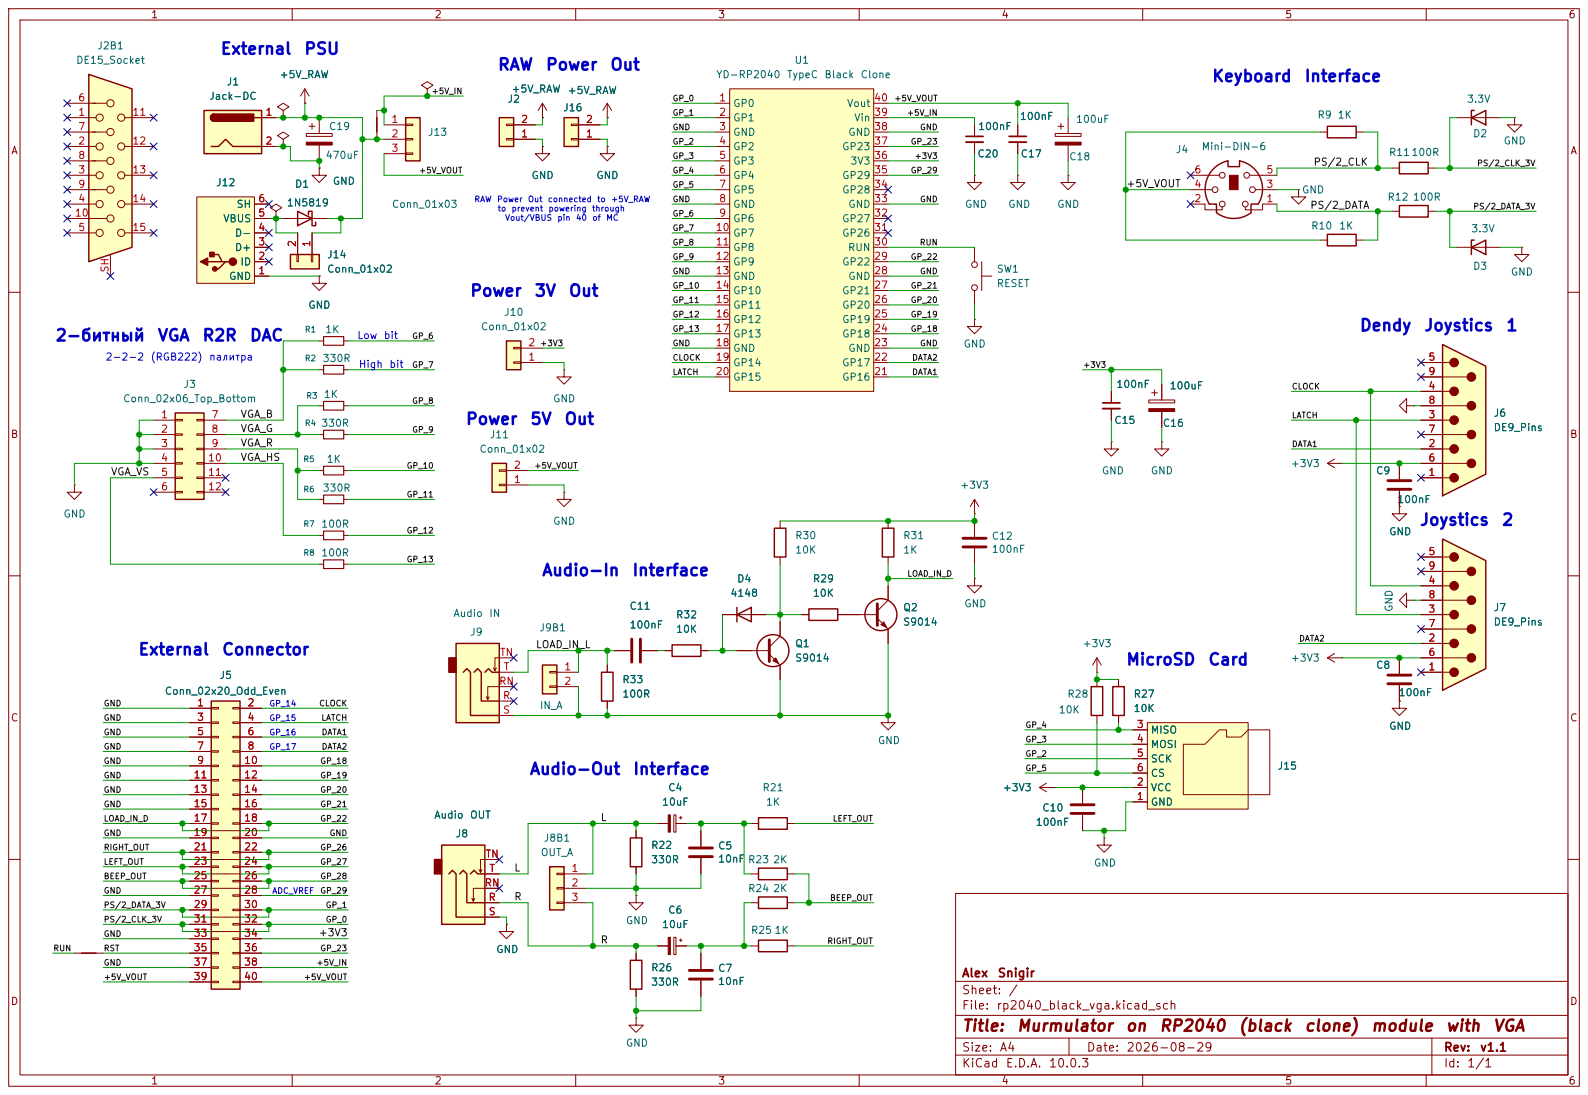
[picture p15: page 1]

YD-RP2040 TypeC Black Clone

RAW Power Out connected to +5V_RAW
to prevent powering through

2 | 8 VGA_G
4 | VGA_HS 10

Sheet: /
File: rp2040_black_vga.kicad_sch
Title: Murmulator on RP2040 (black clone) module with VGA

Size: A4 | Rev: v1.1
KiCad E.D.A. 10.0.3 | Id: 1/1

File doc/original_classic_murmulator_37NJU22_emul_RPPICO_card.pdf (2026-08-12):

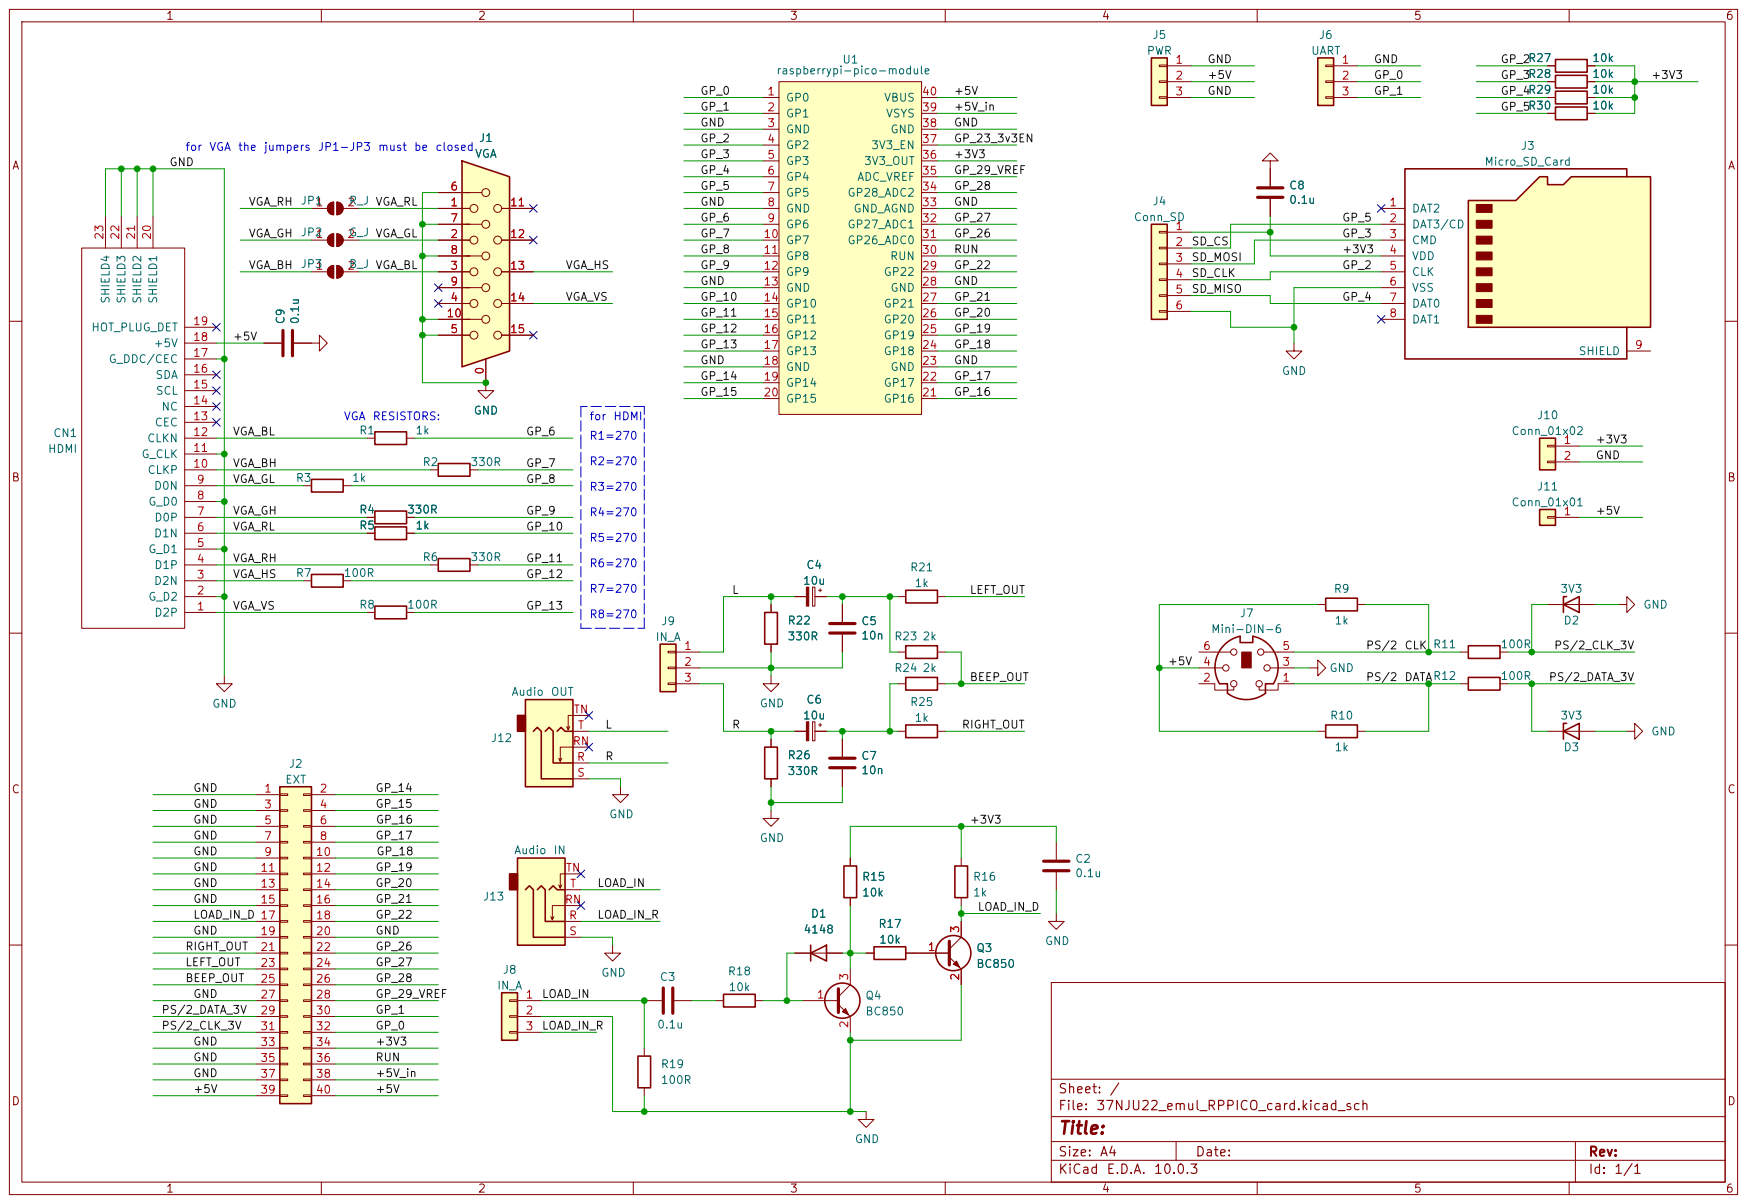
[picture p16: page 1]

for HDMI for VGA the jumpers JP1-JP3 must be closed
VGA_BL VGA_GL GND
VGA_RL VGA_BH

PS/2 DATA PS/2 CLK

Size: A4 | Rev:
KiCad E.D.A. 10.0.3 | Id: 1/1

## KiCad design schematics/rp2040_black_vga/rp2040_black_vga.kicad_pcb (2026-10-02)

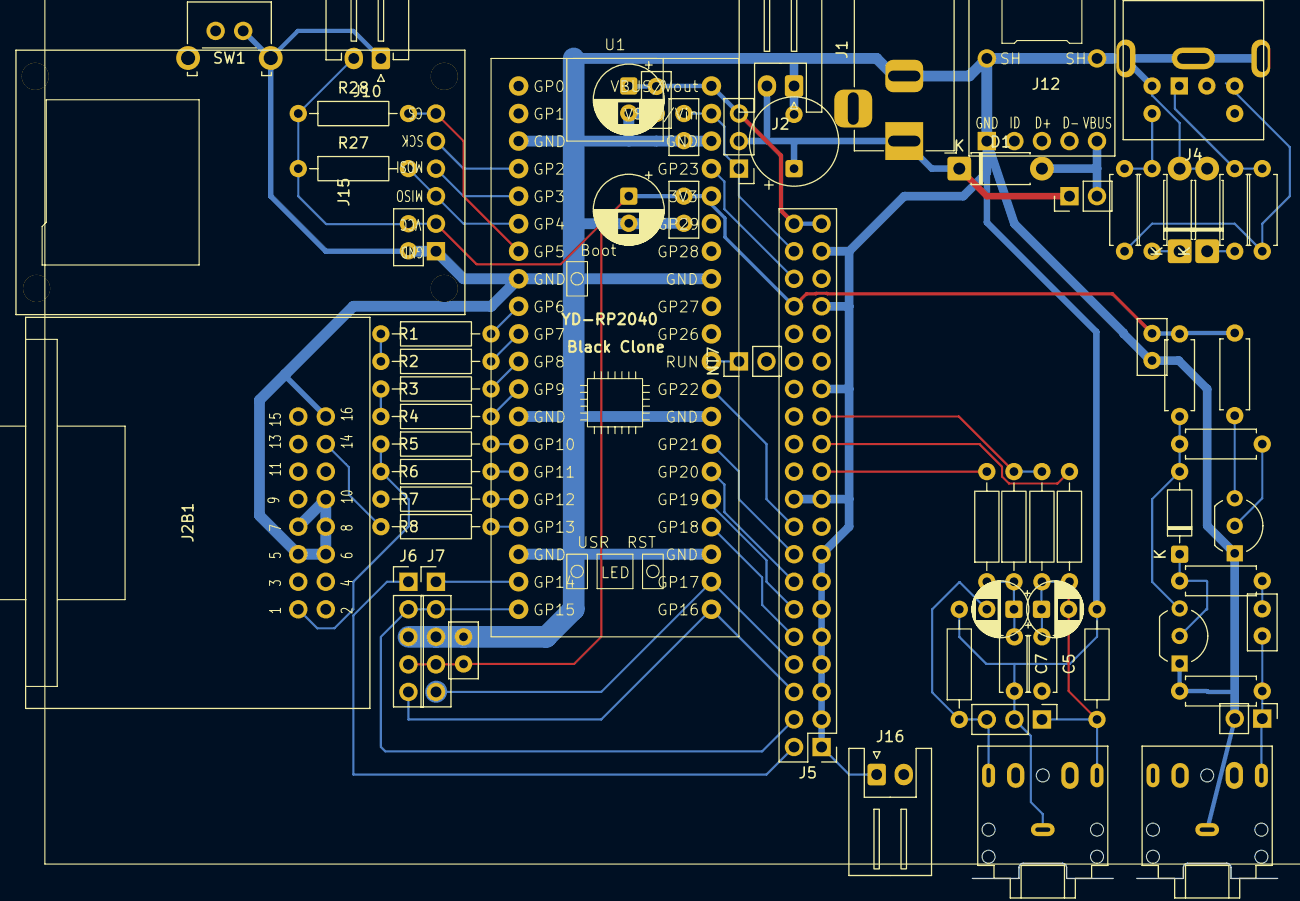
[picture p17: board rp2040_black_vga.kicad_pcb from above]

Board: 2 copper layers, 65 parts (0 on the bottom side), 58 nets.

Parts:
C4, C6: 10uF; CP_Radial_D5.0mm_P2.50mm
C5, C7: 10nF; C_Disc_D5.0mm_W2.5mm_P5.00mm
C8, C10, C11, C12, C15, C17, C20: 100nF; C_Disc_D5.0mm_W2.5mm_P2.50mm
C16, C18: 100uF; CP_Radial_D6.3mm_P2.50mm
C19: 470uF; CP_Radial_Tantal_D8.0mm_P5.00mm
D1: 1N5819; D_DO-41_SOD81_P7.62mm_Horizontal
D2, D3: 3.3V; D_DO-41_SOD81_P7.62mm_Horizontal
D4: 4148; D_DO-35_SOD27_P7.62mm_Horizontal
J1: Jack-DC; BarrelJack_Horizontal
J2, J16: Conn_01x02; JST_XH_S2B-XH-A_1x02_P2.50mm_Horizontal
J2B1: DE15_Socket; VGA_DR15P_Module
J4: Mini-DIN-6; Connector_Mini-DIN_Female_6Pin_2rows
J5: Conn_02x20_Odd_Even; PinHeader_2x20_P2.54mm_Vertical
J6, J7: DE9_Pins; DB9_PinHeader_1x05_P2.54mm_Pins_4,3,8,6,2
J8: Audio OUT; Jack_3.5mm_CUI_SJ1-3525N_Horizontal
J8B1: OUT_A; PinHeader_1x03_P2.54mm_Vertical
J9: Audio IN; Jack_3.5mm_CUI_SJ1-3525N_Horizontal
J9B1: IN_A; PinHeader_1x02_P2.54mm_Vertical
J10: Conn_01x02; JST_XH_S2B_1x02_P2.50mm_Horizontal
J12: USB_Micro_Module_15x13.5mm
J13: Conn_01x03; PinHeader_1x03_P2.54mm_Vertical
J14: Conn_01x02; PinHeader_1x02_P2.54mm_Vertical
J15: MicroSD_Module_41.5x24.5mm
NT7: NetTie_2; PinHeader_1x02_P2.54mm_Vertical
Q1, Q2: S9014; TO-92_Inline_Wide_S9014
R1, R3, R5, R21, R25: 1K; R_Axial_DIN0207_L6.3mm_D2.2mm_P10.16mm_Horizontal
R2, R4, R6, R22, R26: 330R; R_Axial_DIN0207_L6.3mm_D2.2mm_P10.16mm_Horizontal
R7, R8: 100R; R_Axial_DIN0207_L6.3mm_D2.2mm_P10.16mm_Horizontal
R9, R10, R31: 1K; R_Axial_DIN0207_L6.3mm_D2.5mm_P7.62mm_Horizontal
R11, R12, R33: 100R; R_Axial_DIN0207_L6.3mm_D2.5mm_P7.62mm_Horizontal
R23, R24: 2K; R_Axial_DIN0207_L6.3mm_D2.2mm_P10.16mm_Horizontal
R27, R28: 10K; R_Axial_DIN0207_L6.3mm_D2.2mm_P10.16mm_Horizontal
R29, R30, R32: 10K; R_Axial_DIN0207_L6.3mm_D2.5mm_P7.62mm_Horizontal
SW1: RESET; SW_Tactile_SKHH_Angled
U1: YD-RP2040 TypeC Black Clone; RP2040_Type-C_4MB_black_with_ARGB_LED

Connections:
+3V3: C8.2, C10.2, C12.1, C15.1, C16.1, J5.34, J6.6, J7.6, J10.2, J15.2 (VCC), R27.1, R28.1, R30.1, R31.1, U1.36 (3V3)
+5V_RAW: C19.1, D1.1 (K), J1.1, J2.2, J13.2, J14.1, J16.2
/+5V_IN: C20.1, J5.38, J13.1, U1.39 (Vin)
/+5V_VOUT: C17.1, C18.1, J4.4, J5.39, J5.40, J13.3, R9.1, R10.1, U1.40 (Vout)
/BEEP_OUT: J5.25, R23.2, R24.2
/CLOCK: J5.2, J6.4, J7.4, U1.19 (GP14)
/DATA1: J5.6, J6.2, U1.21 (GP16)
/DATA2: J5.8, J7.2, U1.22 (GP17)
/GP_0: J5.32, U1.1 (GP0)
/GP_1: J5.30, U1.2 (GP1)
/GP_2: J15.5 (SCK), U1.4 (GP2)
/GP_3: J15.4 (MOSI), U1.5 (GP3)
/GP_4: J15.3 (MISO), R27.2, U1.6 (GP4)
/GP_5: J15.6 (CS), R28.2, U1.7 (GP5)
/GP_6: R1.2, U1.9 (GP6)
/GP_7: R2.2, U1.10 (GP7)
/GP_8: R3.2, U1.11 (GP8)
/GP_9: R4.2, U1.12 (GP9)
/GP_10: R5.2, U1.14 (GP10)
/GP_11: R6.2, U1.15 (GP11)
/GP_12: R7.2, U1.16 (GP12)
/GP_13: R8.2, U1.17 (GP13)
/GP_18: J5.10, U1.24 (GP18)
/GP_19: J5.12, U1.25 (GP19)
/GP_20: J5.14, U1.26 (GP20)
/GP_21: J5.16, U1.27 (GP21)
/GP_22: J5.18, U1.29 (GP22)
/GP_23: J5.36, U1.37 (GP23)
/GP_26: J5.22, U1.31 (GP26)
/GP_27: J5.24, U1.32 (GP27)
/GP_28: J5.26, U1.34 (GP28)
/GP_29: J5.28, U1.35 (GP29)
/L: C4.2, J8.T, J8B1.1, R22.1
/LATCH: J5.4, J6.3, J7.3, U1.20 (GP15)
/LEFT_OUT: J5.23, R21.2
/LOAD_IN_D: J5.17, Q2.C, R31.2
/LOAD_IN_L: C11.2, J9.T, J9B1.1, R33.1
/PS/2_CLK: J4.5, R9.2, R11.1
/PS/2_CLK_3V: D2.1 (K), J5.31, R11.2
/PS/2_DATA: J4.1, R10.2, R12.1
/PS/2_DATA_3V: D3.1 (K), J5.29, R12.2
/R: C6.2, J8.R, J8B1.3, R26.1
/RIGHT_OUT: J5.21, R25.2
/RST: J5.35, NT7.2
/RUN: NT7.1, SW1.1, U1.30 (RUN)
/VGA_B: J2B1.3, R1.1, R2.1
/VGA_G: J2B1.2, R3.1, R4.1
/VGA_HS: J2B1.13, R7.1
/VGA_R: J2B1.1, R5.1, R6.1
/VGA_VS: J2B1.14, R8.1
GND: C5.2, C7.2, C8.1, C10.1, C12.2, C15.2, C16.2, C17.2, C18.2, C19.2, C20.2, D2.2 (A), D3.2 (A), J1.2, J2.1, J2B1.5, J2B1.6, J2B1.7, J2B1.8, J2B1.10, J4.3, J5.1, J5.3, J5.5, J5.7, J5.9, J5.11, J5.13, J5.15, J5.19, J5.20, J5.27, J5.33, J5.37, J6.8, J7.8, J8.S, J8B1.2, J9.S, J9B1.2, J10.1, J12.1 (GND), J12.6 (SH), J15.1 (GND), J16.1, Q1.E, Q2.E, R22.2, R26.2, R33.2, SW1.2, U1.3 (GND), U1.8 (GND), U1.13 (GND), U1.18 (GND), U1.23 (GND), U1.28 (GND), U1.33 (GND), U1.38 (GND)
unnamed: C4.1, C5.1, R21.1, R23.1
unnamed: C6.1, C7.1, R24.1, R25.1
unnamed: C11.1, R32.1
unnamed: D1.2 (A), J12.5 (VBUS), J14.2
unnamed: D4.2 (A), Q1.C, R29.1, R30.2
unnamed: D4.1 (K), Q1.B, R32.2
unnamed: Q2.B, R29.2

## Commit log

2026-08-12 audio-in added
    [rp2040_black_vga.kicad_pcb, rp2040_black_vga.kicad_sch]
2026-08-17 update schematics
    [rp2040_black_vga.kicad_sch]
2026-10-02 3d models, doc and pcb update
    [DB9_x2_mount.3mf, DB9_x2_mount.SLDPRT, DB9_x2_mount.STL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]
2026-10-07 doc update, 3d models
    [Box_Bottom.3mf, Box_Bottom.SLDPRT, Box_Bottom.STL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]
2026-10-08 box 3d models
    [Box_Bottom.3mf, Box_Bottom_v2.3mf, Box_Cover_v2.3mf]
